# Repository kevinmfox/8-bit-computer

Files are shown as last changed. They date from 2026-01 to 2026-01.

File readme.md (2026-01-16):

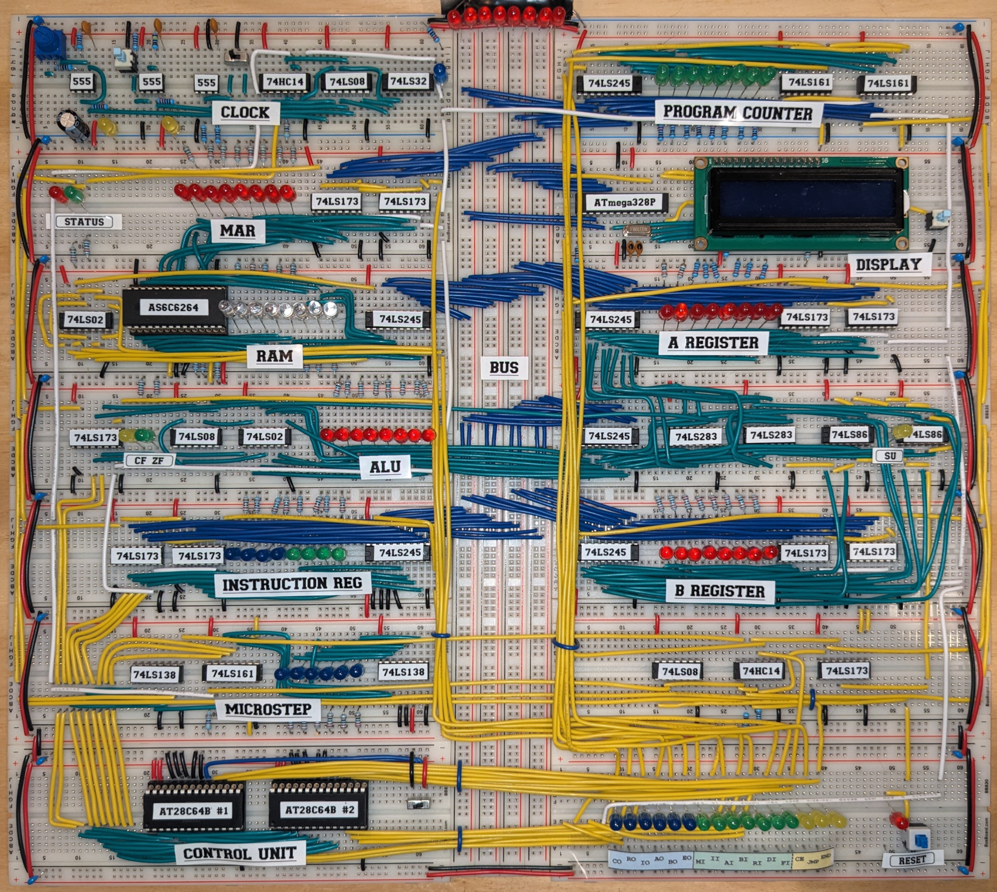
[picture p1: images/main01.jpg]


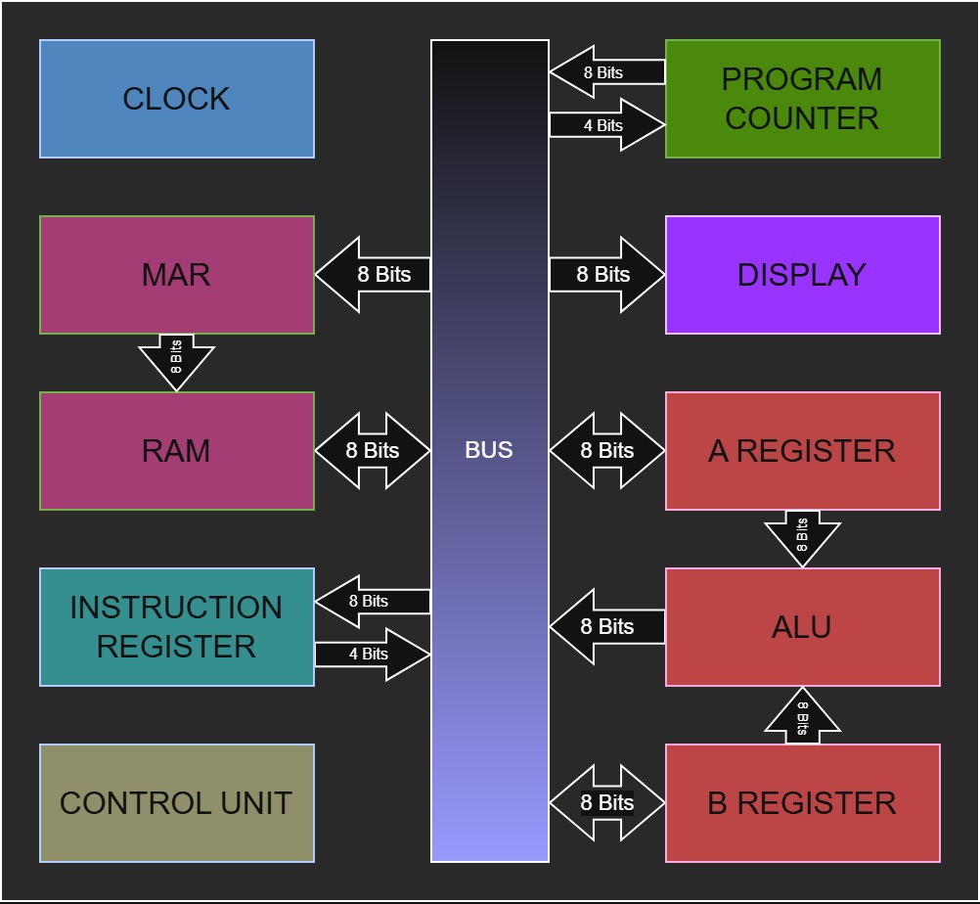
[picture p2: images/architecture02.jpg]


Credit to [diagrams.net](https://app.diagrams.net) for making the above image easy to do.

## Background

I came across Ben Eater's "8-Bit Computer" video series several years ago, and I thought it would be a really interesting project to take on. Over the course of the majority of my career (and most of my hobbies), my understanding of "computer systems" has been primarily focused on *things above the hardware layer*. 

In my early days I spent some time building systems, servers, etc., but when *the cloud* came along, much of that was *abstracted away from me*. I have some minor experience programming in assembly, and good amount of experience with higher-level programming languages. I'm also comfortable explaining computer architecture at an academic or conceptual level, but what was missing was a deeper, hands-on, understanding on how a computer works at the hardware layer. Actually building an "A Register". Having the Control Unit tell a register to put information on the bus, and having RAM store that information for later use. Understanding how the CPU clock works at the electrical level. Understanding how each integrated circuit plays its part in each CPU module...and so on. 

What better way to *bridge these gaps* than to build a super-simple 8-bit system.

I did post a video to YouTube covering much of this build as well, that can be found here: [https://youtu.be/7FzZS5qhdJ4](https://youtu.be/7FzZS5qhdJ4])

## Credit Where Credit's Due

Full credit to Ben Eater, the schematics on his website, and his tutorial videos. His videos were the original inspiration to attempt this project, and without those, I a) probably wouldn't have even thought to attempt this; and b) even if I did, building it would have taken me orders of magnitude longer.

YouTube series: https://www.youtube.com/watch?v=HyznrdDSSGM

Website: https://eater.net/8bit (https://eater.net/)

## Table of Contents

[The Build](build/readme.md)

Parts I used, my thoughts, learnings, observations, "gotchas", reference images, architecture stuff, etc. as I worked through the build.

[Schematics](schematics/readme.md)

Mostly so that, at some point in the future, I can reference how I did any of this.

[Instruction Set Architecture (ISA)](isa.md)

The 'spec' for my instruction set. Instructions, registers, flags, execution cycle, etc. Capabilities of the system and hardware expectations.

[Microarchitecture](microarchitecture.md)

My implementation of the ISA, covering the Modules, Control Signals, and other behaviour (e.g. system reset).

[EEPROM Programming - Python](/python/readme.md#microcode-generation)

The Python program (`generate_microcode.py`) I used to convert my control signals into *firmware* for my EEPROMs.

[EEPROM Programming - Arduino](/arduino/readme.md#eeprom-programmer)

Actually getting the EEPROM *firmware* onto the chips.

[The Compiler](/python/readme.md#compiling-programs)

A look at the Python compiler I used (`compile.py`) to convert my assembly files to machine code.

[Program Execution](/arduino/readme.md#ram-programmer)

How I took a compiled program and loaded it onto the system, and ran it.

## Other

The datasheets I used for the project can be found in the [datasheets](datasheets/) folder.

## What's Next?

I have a lot of thoughts on what I could do *next* as an extension to this project, but I promised myself I'd *step away* from it for a month or two.

Ideas for *Phase 2*:
- I think when the weather gets warmer I may construct a *shadow box* to store this project in (a fun link to my woodworking hobby)
- I'd like to learn how to convert this, or pieces of this, into PCBs
- If I do it (or similar) again, I may try to make the following architectural changes:
    - Either a 16-bit Instruction Register with an 8-bit Opcode and 8-bit Operand, or two seperate registers
    - An additional Register, just because you can never have too many ;)
    - Three EEPROM chips to support up to (e.g.) 24 control lines
    - Potentially some sort of user input (but that would require a bunch of other things)

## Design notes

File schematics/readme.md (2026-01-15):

# Schematics

## Overview

Schematics were built using KiCad: https://www.kicad.org/

It's free, open source, and for my purposes worked very well.

If I had my time back, I would have learned to use this *at the start*, or at least as I was working through the build. I tracked wire mappings and pinouts using a giant 700+ row spreadsheet. And, although that worked for me, it would have been way easier to troubleshoot had I just used the *right tool for the job* (e.g. KiCad).

The **Main** folder includes the main schematics for the actual build. 

The **Tooling** folding includes some additial schematics for things like the EEPROM and RAM programmers.

## Reading These With KiCad

Go get KiCad: https://www.kicad.org/

If you double-click on the `Main.kicad_pro` that'll open up the main build, and you can navigate through the schematics - it doesn't take much to learn how to crawl around these files. You can also open up individual schematics by double-clicking any `*.kicad_sch` file (e.g. `RAM Programmer.kicad_sch`).

## PDF Versions

I've included a few PDFs in the `schematics` folder. If you don't have or don't want to use KiCad, these can be used to review/map the build as well.

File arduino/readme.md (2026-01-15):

#  Arduino Programs

This area outlines the Arduino programs I used throughout the build. The assumption here is that you have an Arduino to use.

Below I've outlined the main programs, requirements, as well as some helpful notes for each.

Realistically, you probably shouldn't *tackle* the ROM programming until you're fairly certain what control signals you want your Control Unit to emit given specific inputs. This would necessarilly happen near the end of the build. Similarily, the RAM programming probably shouldn't be a priority until you've got your EEPROMs close to working.

## Display

This is the only aspect of the build where I think I *cheated* a little. In Ben Eater's original build (https://eater.net/8bit/output), he used four 7-segment displays along with a bunch of logic to produce output. I wanted to have something I could use to: a) troubleshoot easily; and, b) have multiple display modes (e.g. Hex, Binary, Decimal).

For example, I could tie `PIN 19` (`LATCH_MODE`) on the ATmega `LOW`, and the Display would continuously show what was on the bus (helpful for troubleshooting).

Requirements:
- Arduino for programming
- `ATmega328P` chip that will live on the build
- `1602A` 2-line display
- (optional) A push-button that could be used to switch modes

I would program the ATmega chip using the Arduino, and then put it on the board. It hasn't moved since.

Build info for the display can be found [here](/build/readme.md#display).

## EEPROM Programmer

Before programming these chips, you'll need to generate the actual ROM images. This can be done using the `generate_microcode.py` Python script (which assumes a bunch of other things). More details here: [Python](/python/readme.md#eeprom-programming)

I programmed each chip individually. Remove one from the board, program it, put it back, and repeat.

The `eeprom_programmer` folder contains the `microcode_images.h` file that was used for my project.

The sketch will prompt you to select which EEPROM you're programming.

Requirements:
- Arduino for programming
- Two EEPROM chips - I used `AT28C64B` chips
- The `microcode_images.h` file that holds the actual ROM images

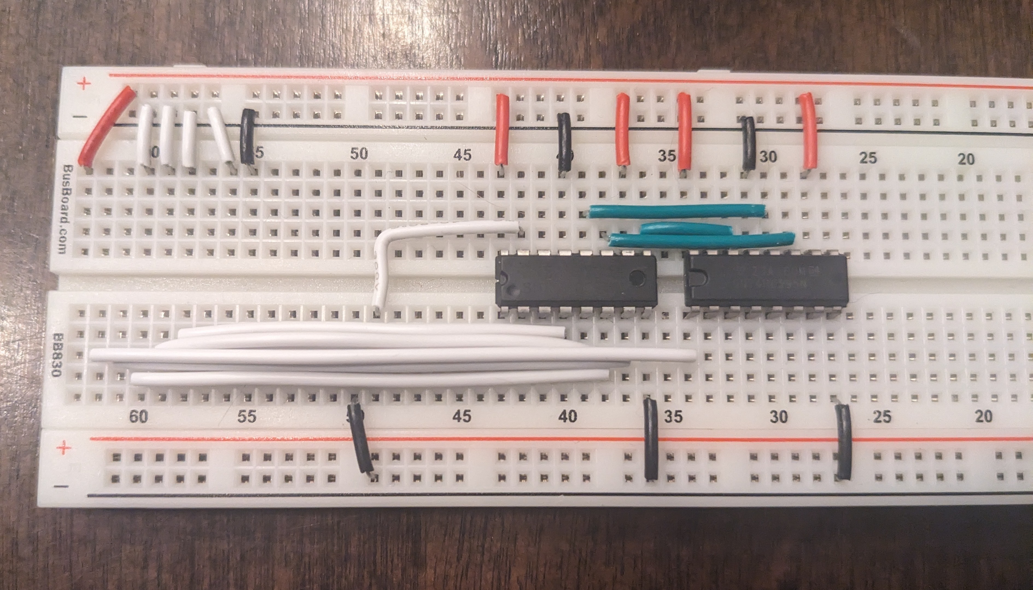
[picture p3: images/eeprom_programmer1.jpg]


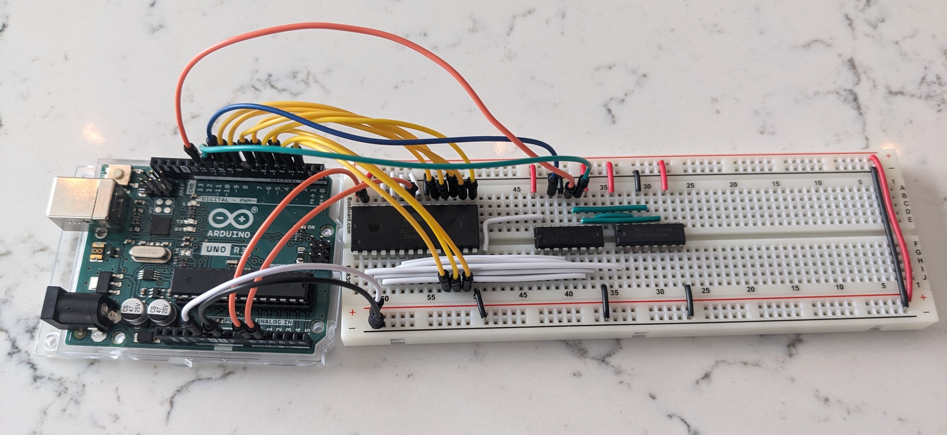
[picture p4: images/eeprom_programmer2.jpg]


## RAM Programmer

Similar to the EEPROM, you'll need to programs that can be run before you program the RAM chip. This also requires that the Control Unit EEPROMs be programmed (and preferably running properly).

Programs can be *compiled* using the `compile.py` Python script. More details here: [Python](/python/readme.md#compiling-programs)

The `ram_programmer` folder contains the `programs.h` file that was used for my project. It includes four test programs to ensure control signals are working as expected, and a couple *blinky light* programs for fun.

Requirements:
- Arduino for programming
- A RAM chip - I used `AS6C6264`
- Programs saved into `programs.h`
- Functional bus lines to read and write to the RAM chip
- Functional `CLK`, `/RI`, `/RO`, `/MI` lines to control program writing to the RAM chip

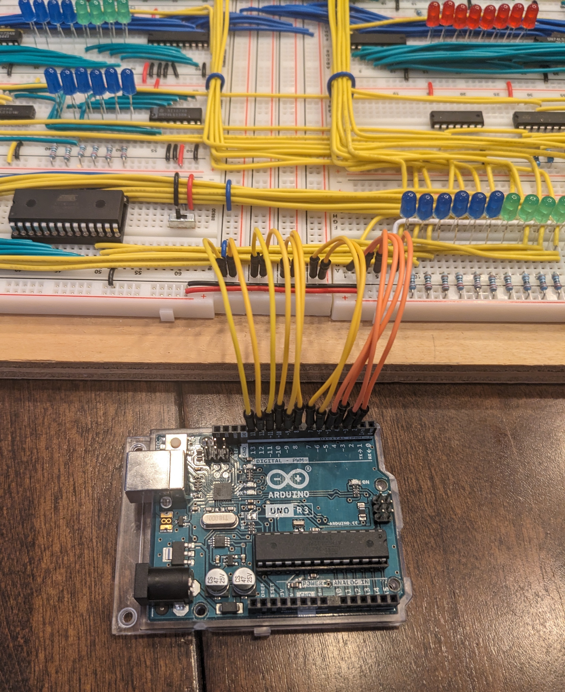
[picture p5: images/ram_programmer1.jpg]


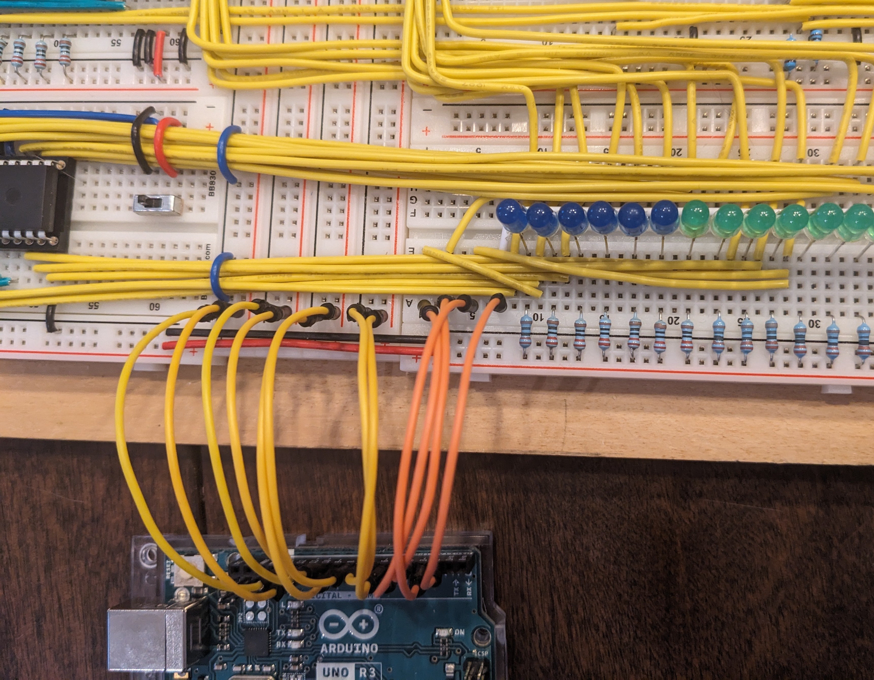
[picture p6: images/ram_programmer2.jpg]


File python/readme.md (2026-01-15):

## Microcode Generation

The `generate_microcode.py` Python script will generate the microcode from a given "signal truth table" (`assets\microcode.csv`) that can be put on EEPROMs.

The script can certainly be modified to take another or differntly formatted input, but the general idea is take your CPU input signals, and convert those into expected output signals.

In my case, the input signals were:
- `Opcode` - Four bit binary representation (e.g. `0101`)
- `T-Step` - Represented as `T0` through `T5` (depdnding on the instruction)
- `CF` - The state of the Carry Flag (`0` or `1`)
- `ZF` - The state of the Zero Flag (`0` or `1`)

The `T-Step`, `CF`, and `ZF` inputs can also take wildcards (`*`) which will be *expanded* to cover all posibilities.

The outputs will be whatever control signals you want active given the inputs.

For all instructions, the final step is an `END` signal, which tells the Microstep Counter to go back to `T0`.

In my case, I had my `assets\microcode.csv` file represented as active-high (i.e. 1 = ON), but the actual script will generate active-low signals, as that's what my board expected.

Note the `Address`, and `Mnemonic` fields in the `microcode.csv` file aren't actually used in the Python script, but are there simply for reference.

I programmed an Arduino to program my EEPROM chips. Steps on getting the generated microcode onto an EEPROM chip can be found [here](/arduino/readme.md#eeprom-programmer).

Sample commands:
- `python .\generate_microcode.py`

## Compiling Programs

The actual `compile.py` Python script is not much more than a generic text parser and mapping algorithm. Read a line; parse/extract/scrape certain portions; make decisions based on the inputs; output some other text. I'm not trying to downplay the importance of this, or suggest all compilers are this simple (they're not), but provided your instruction set is *simple*, and you are rigid in what you allow for your assemlby language, it's fairly straightforward. 

The compiled instructions obviously have to align with the microcode you've put on your ROMs.

So, if you give an instruction such as `ADI 0x8`, the expected compiled line would be:
- Opcode = `ADI` = `0101` or `0x5`
- Operand = `0x8` = `1000` or `0x8`
- Instruction = `0101 1000` or `0x58`

Given the limitation of a 4-bit Operand, you should be cautious when compiling programs that use `STA` instruction. This instruction will *store* the value of the A Register into the memory address of the Operand. But, if your programs runs into that same space, you may have inadvertently overwritten some of your program. My compiler doesn't check for this, and I didn't think I needed it to until I did this about a dozen times to myself ;).

The compiler supports some basic sanity checks:
- Address out of range for my architecture (i.e. referencing something above 0xF)
- Invalid instructions
- Missing Operands or Operands on instructions that expect none (e.g. `NOP`)

The compiler supports:
- Jump labels
- Using hex (e.g. `0xF`), binary (e.g. `0b1111`) or decimal (e.g. `15`) for Operands
- Comments

Given a text file input (by convention I've labelled these ASM files), it will print the compiled code to screen. This can be copied/pasted into the `programs.h` file for the [Arduino Programmer](/arduino/readme.md#ram-programmer).

I used an Arduino to program my RAM chip while it was on the board. Steps on getting these programs onto the board can be found [here](/arduino/readme.md#ram-programmer).

Sample commands:
- `python .\compile.py --program-name TEST assets\program-test01.asm`
- `python .\compile.py --program-name DEMO01 --print-summary .\assets\program-demo-01.asm`

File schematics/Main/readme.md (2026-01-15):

# Main Schematics

Once you load the `main.kicad_pro` file in KiCad, it's easy enough to see the main layout and click through the various module schematics.

While I made efforts to align my schematics to what I actually built, there is some variation. This was usually caused by either space constraints or moving something to a location where it would *make more sense*. A few examples: 

- The build has the Status Lights (Red = Halt; Green = Running) on the Memory Address Register board.
- The physical ALU spans across two horizontal breadboard, where my schematic may imply otherwise.
- The build has the `HLT` and `SU` decoding on the Microstep Counter board (there was just more room) vs. the Instruction Register.
- The build has a completely separate board for some *auxiliary* chips used by the Control Unit due to space constraints, and it also holds the `74LS173` chip for the `SU` Flag. I also used the `74HC14` inverter on this board to help with other inversions.
- The Control Unit spans across two breadboards (chips & LEDs).

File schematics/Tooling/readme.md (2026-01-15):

# Tooling Schematics

Both the EEPROM and RAM programmer used an Arduino Uno for programming.

More detailed requirements can be found in the respective `arduino` programs. These sketches simply outline how I programmed these chips.

## EEPROM Programmer

Used the sketch found in [arduino/eeprom_programmer](../../arduino/eeprom_programmer).

Each EEPROM chip was programmed individually (i.e. remove chip from board; program it; put it back; repeat).

## RAM Programmer

Used the sketch found in [arduino/ram_programmer](../../arduino/ram_programmer).

The Arduino was hooked up directly to the project via the bus and several control lines (`CLK`, `/MI`, `/RI`, `/RO`).

It's important that the Arduino is the only thing driving the bus, that the Control Unit is 'disconnected', and the Clock isn't running. In my build, I used a toggle switch to *disconnect* the Control Unit and stop the Clock.

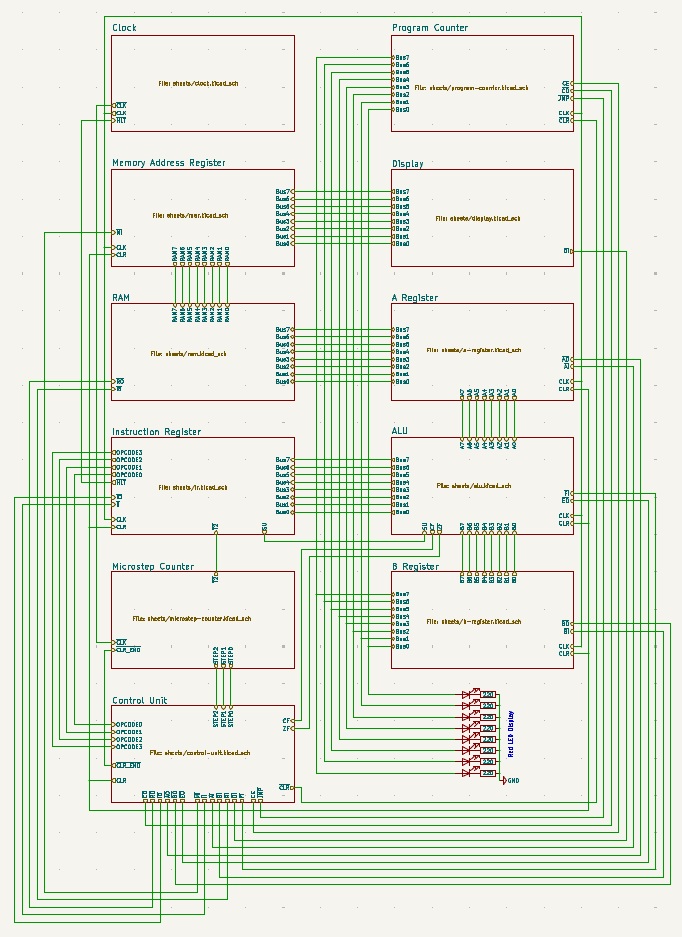
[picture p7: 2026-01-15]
images/architecture01.jpg

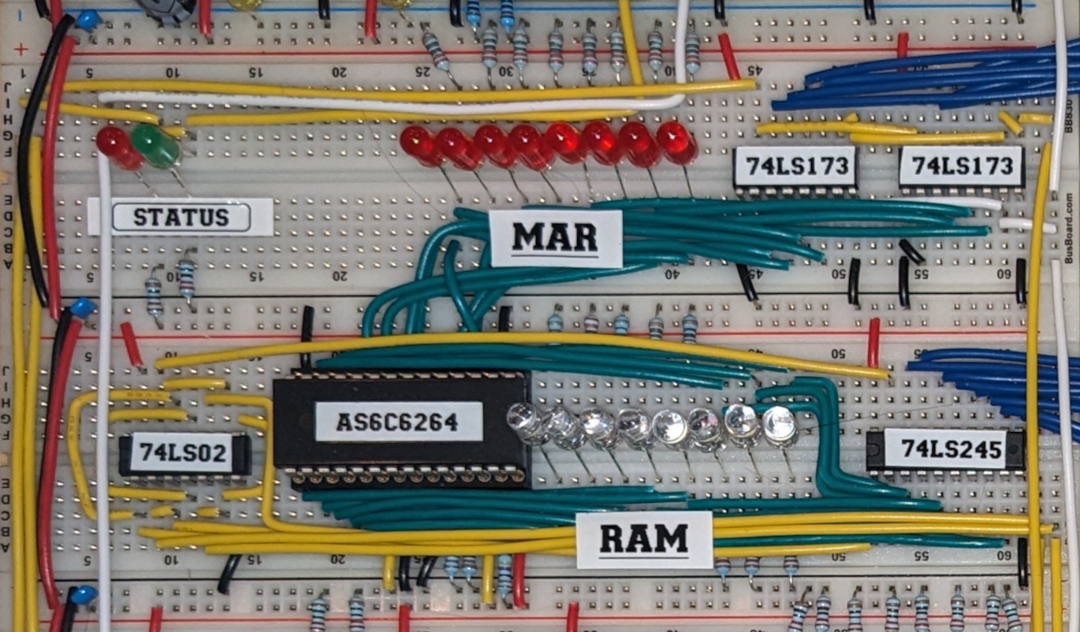
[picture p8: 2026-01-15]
images/mar_ram01.jpg

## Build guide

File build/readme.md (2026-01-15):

# The Build

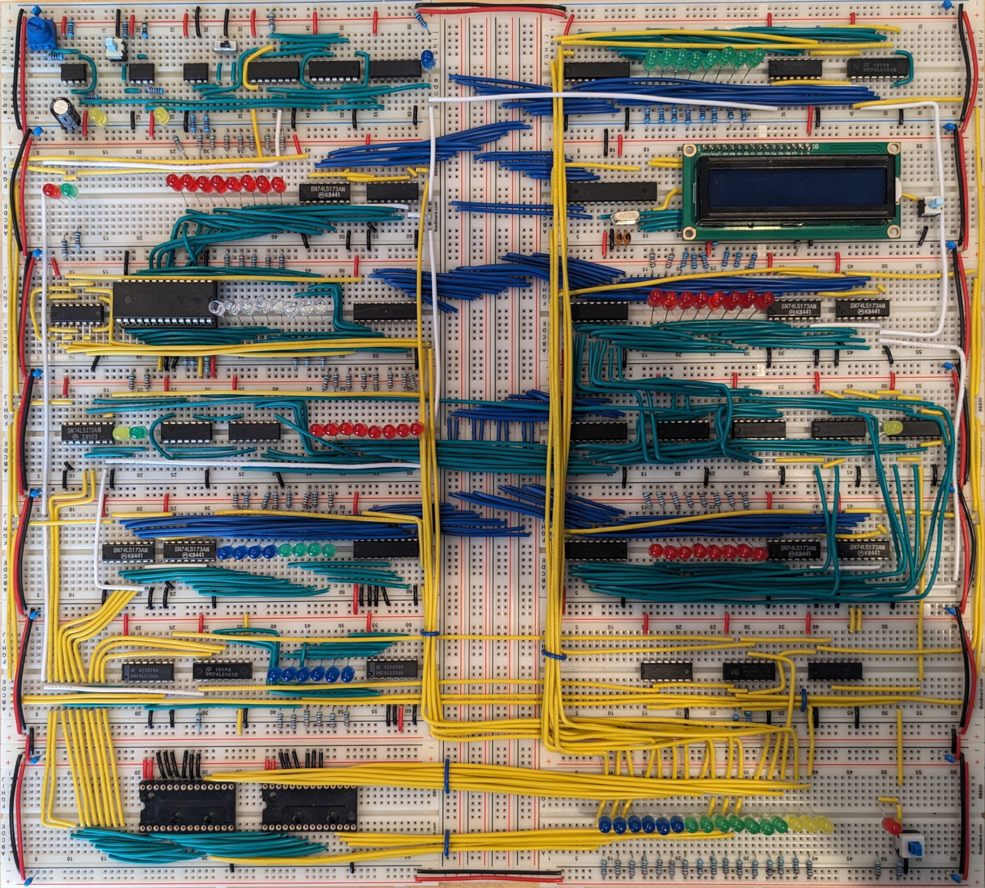
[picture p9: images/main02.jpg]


## Inventory

Here's a rundown of all the parts I used. It should be *pretty close* to accurate ;)

Notes:
- I only used a single 100 nF decoupling capacitor per breadboard module. I know *best practice* is to have a decoupling capacitor on every IC. I didn't have any issues, but take note.
- I used [BB830 breadboards](https://www.amazon.ca/BusBoard-Prototype-Systems-BB830-Solderless/dp/B0040Z4QN8) almost exclusively (I had a couple laying around before I started). Seriously, if you're going to do this, don't go cheap on breadboards. I tried saving a couple dollars at a local electronics shop, and the boards were inconsistent at best.
- For wiring I bought two of [these kits](https://www.amazon.ca/dp/B0CM2Y7V1Z). For those interested, I used: 10.4 feet or red wire, 13.7 feet of white wire, 14.3 feet of black wire, 30.0 feet of blue wire, 57.3 feet of yellow wire, and 59.0 feet of green wire. 184.7 feet of wire (not account for mistakes or rework!)

| Type | Value | Quantity | Notes |
|---|---|---|---|
| Capacitor | 1 µF | 1 | 555 astable capacitor |
| Capacitor | 10 nF | 3 | 555 signal conditioning |
| Capacitor | 100 nF | 14 | Decoupling capacitors - one per breadboard module |
| Capacitor | 22 pF | 2 | For the 16 MHz Crystal on the ATmega driving the Display |
| LED | 5 mm Yellow | 6 | Generally used for Flags and a few Control indicators |
| LED | 5 mm Green | 21 | Program Counter, Operand, and input Control indicators |
| LED | 5 mm Red | 42 | MAR, A & B Registers, ALU result, and Bus indicators |
| LED | 5 mm White | 8 | Only used on the RAM module |
| LED | 5 mm Blue | 17 | Clock pulse, Opcode, Microstep Counter, and output Control indicators |
| Resistor | 220 Ω | 95 | LED current-limiting resistors, including the 1602A display |
| Resistor | 1 kΩ | 3 | 555 astable timing (R1), 555 monostable debounce, and 1602A display contrast |
| Resistor | 330 Ω | 1 | 555 astable timing (R2) |
| Resistor | 1 MΩ | 1 | 555 monostable timing |
| Resistor | 4.7 kΩ | 6 | Various pull-ups and pull-downs |
| Potentiometer | 0-200 kΩ | 1 | Clock speed adjustment (555 astable) |
| Switch | Slide switch | 2 | Clock mode, and Control Unit enable/disable |
| Push Button | Momentary | 3 | Clock step, Display mode, and Reset buttons |
| Display | 1602A LCD | 1 | Arduino-driven output display |
| Crystal | 16 MHz | 1 | ATmega328P clock source |
| IC | LM555 | 3 | Clock module (astable, monostable, selector) |
| IC | ATmega328P | 1 | Display controller |
| IC | 74LS08 | 3 | AND gates - Clock, ALU, and Control Unit logic |
| IC | 74LS245 | 6 | 8-bit bus transceivers |
| IC | 74LS161 | 3 | Binary Counter - Program Counter, Microstep Counter |
| IC | 74LS173 | 10 | Register data - MAR, A, B, IR, Flags |
| IC | 74HC14 | 2 | Schmitt trigger inverters |
| IC | 74LS32 | 1 | OR gates -  Clock |
| IC | 74LS02 | 2 | NOR gates - RAM signal logic, ALU |
| IC | 74LS138 | 2 | 3-to-8 Decoder - IR, Microstep Counter |
| IC | 74LS283 | 2 | Binary adders - ALU |
| IC | 74LS86 | 2 | XOR gates - ALU subtraction |
| Memory | AS6C6264 SRAM | 1 | Main RAM |
| Memory | AT28C64B EEPROM | 2 | Microcode ROMs |
| Breadboard | BB830 | 14 | To connect everything |

## Modules

[Clock Module](#clock-module)

[Program Counter](#program-counter)

[Display](#display)

[Memory Address Register (MAR)](#memory-address-register-mar)

[Random Access Memory (RAM)](#random-access-memory-ram)

[A & B Registers](#a--b-registers)

[Arithmetic Logic Unit (ALU) & Flags](#arithmetic-logic-unit-alu--flags)

[Instruction Register](#instruction-register)

[Microstep Counter](#microstep-counter)

[Auxiliary Board](#auxiliary-board)

[Control Unit](#control-unit)

## Clock Module

The Clock module was an interesting aspect of this build because it serves a distinctly unique purpose compared to all other modules. It's sole purpose is to *emit* a clock pulse - that's it. It could have been a single 555 timer chip, a capacitor, and a couple resistors. It's the ability to select between modes (astable vs. mono), adjust the speed via the potentiometer, and halt the clock that accounts for the bulk of the complexity.

With the exceptions that I kept the LEDs to indicate the astable tick and the mono step, and I used 74HC14 Schmitt invertger to *clean up* and invert my `HLT` and `CLK` signals, what I built was right out of [Ben Eater's tutorials](https://eater.net/8bit/clock).

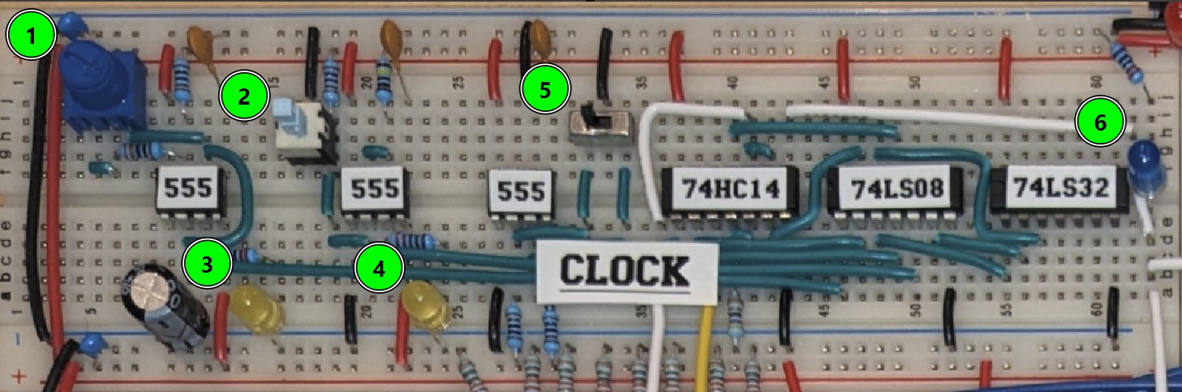
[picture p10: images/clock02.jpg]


- #1 - Potentiometer to adjust the clock speed
- #2 - Pushbutton to send a single pulse (assuming in mono mode)
- #3 - Astable LED
- #4 - Monostable LED
- #5 - Slider to control astable or mono mode
- #6 - Final clock output

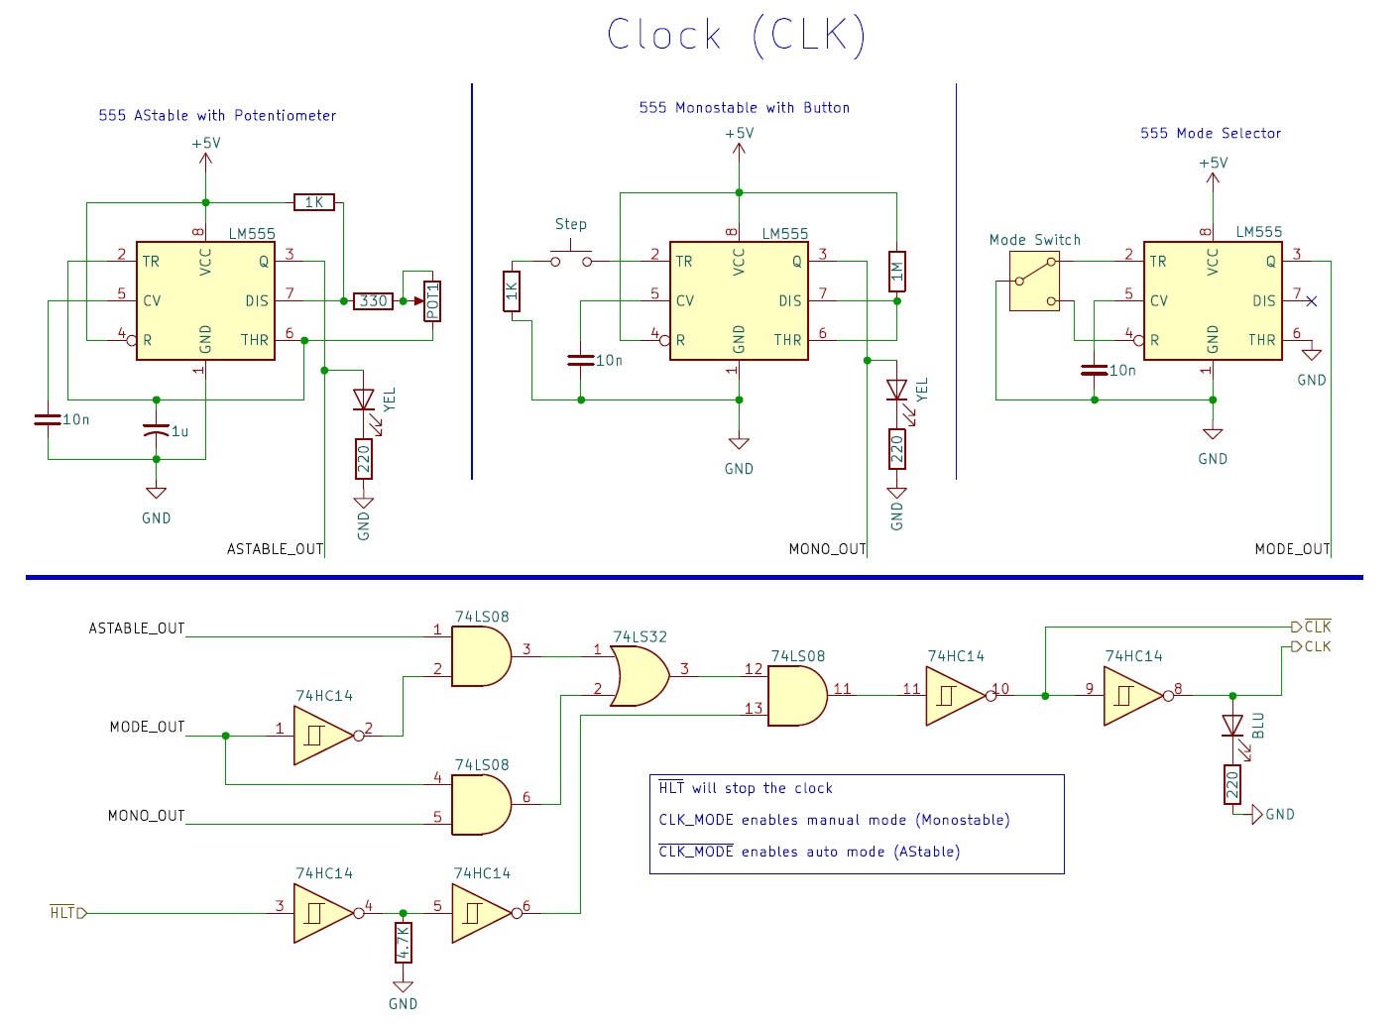
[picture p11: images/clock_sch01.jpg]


## Program Counter

Not much difference here vs. Ben's build with the exception that I made my Program Counter a full 8 bits vs. Ben's 4 bits. Practically speaking, this made little difference, but it did give me the option to do a full 8-bit IR later on (which I didn't), and also allowed me to run the program space beyond 16 bits (which I did on occasion).

I messed this portion of the build up twice! This was the second module I worked on, so I hadn't fully conceptualized the build in my head yet (excuses). My bus runs MSB (left) to LSB (right). The 74LS245 chip, when placed PIN 1 bottom-left, runs opposite - LSB > MSB  (if you're using PIN numbers and labels as your guide). Additionally, the 74LS161s (assuming PIN 1 bottom-left) also runs the same as the 74LS245 - LSB > MSB. I was testing my `JMP` command, and realized the data coming back in from the bus was backwards. So, I ripped it all up, rewired it, and then the data coming from the bus was correct, but the data coming from the Program Counter was entering the bus backwards *sigh*. Got it right on the third attempt.

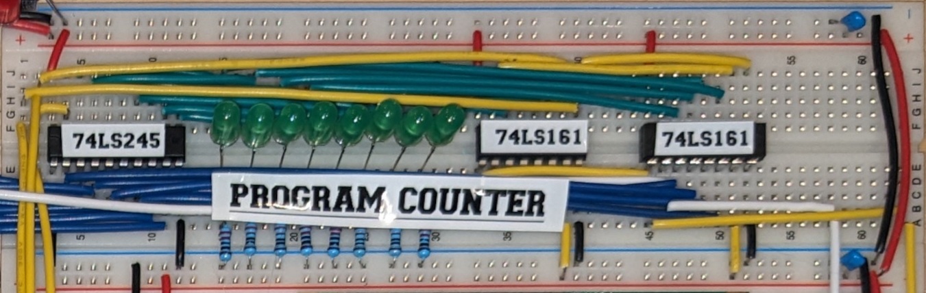
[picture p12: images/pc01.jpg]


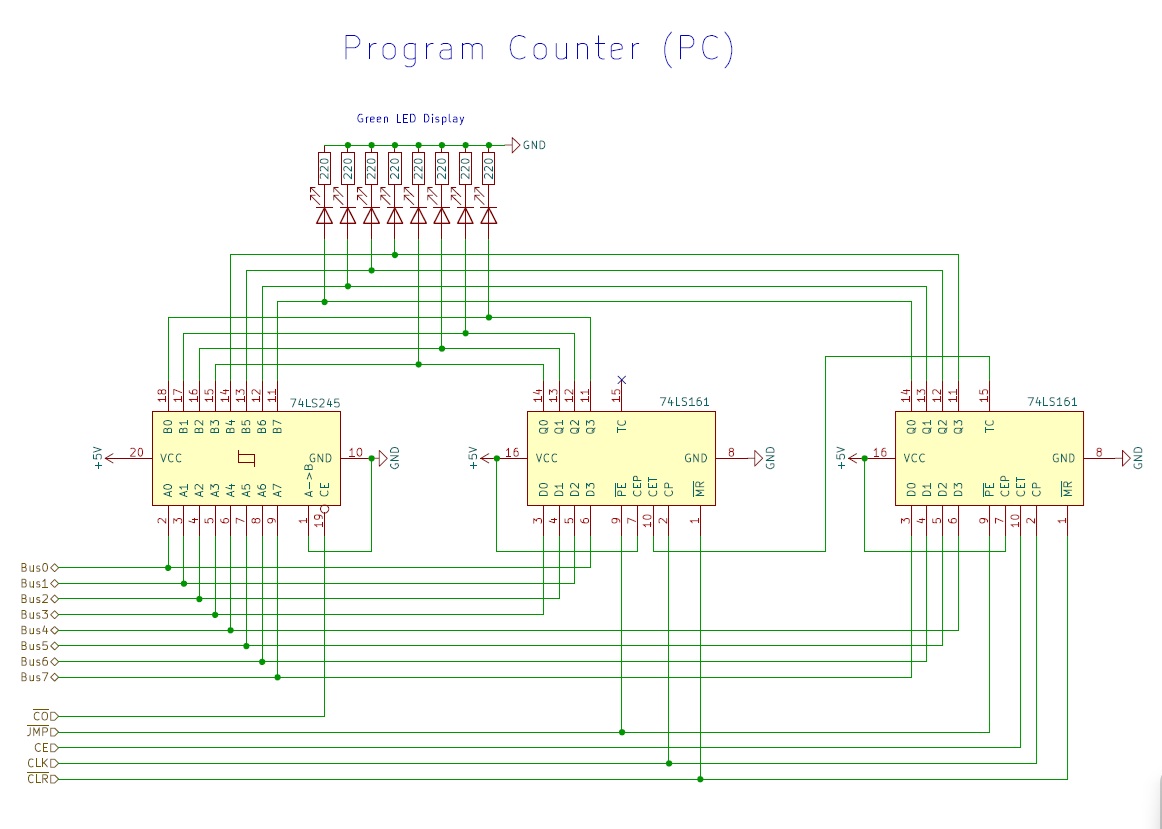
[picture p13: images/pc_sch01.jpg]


## Display

A somewhat controversial *pivot* here ;). This deviated dramatically from Ben's initial build. I *cheated* and used an ATmega328P to run my display output. This (clearly) wasn't about saving space, wires, or chips, but more that I wanted to use the 1602A LED display I had sitting around, and also wanted to be able to view hex, decimal, and binary in a single spot - this solved that. 

I incorporated a pushbutton that would allow me to switch between modes. And I also programmed PIN 19 on the ATmega to allow me to constantly *pull* the bus if it was enabled (wired to ground or pulled low).

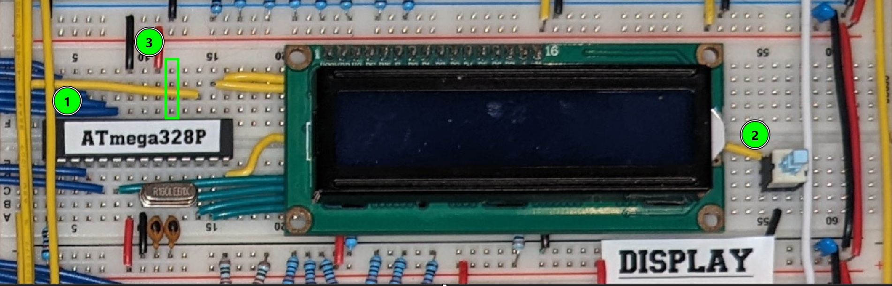
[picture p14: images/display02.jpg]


- #1 - The notorious ATmega chip
- #2 - Pushbutton to change display modes
- #3 - PIN 19 on the ATmega to allow pulling from the bus directly (shown in the image below)

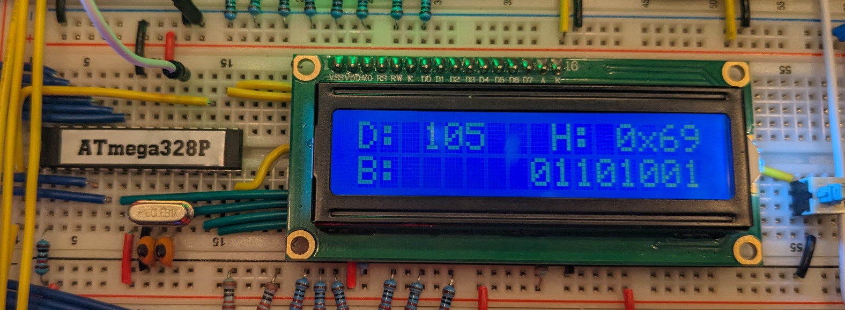
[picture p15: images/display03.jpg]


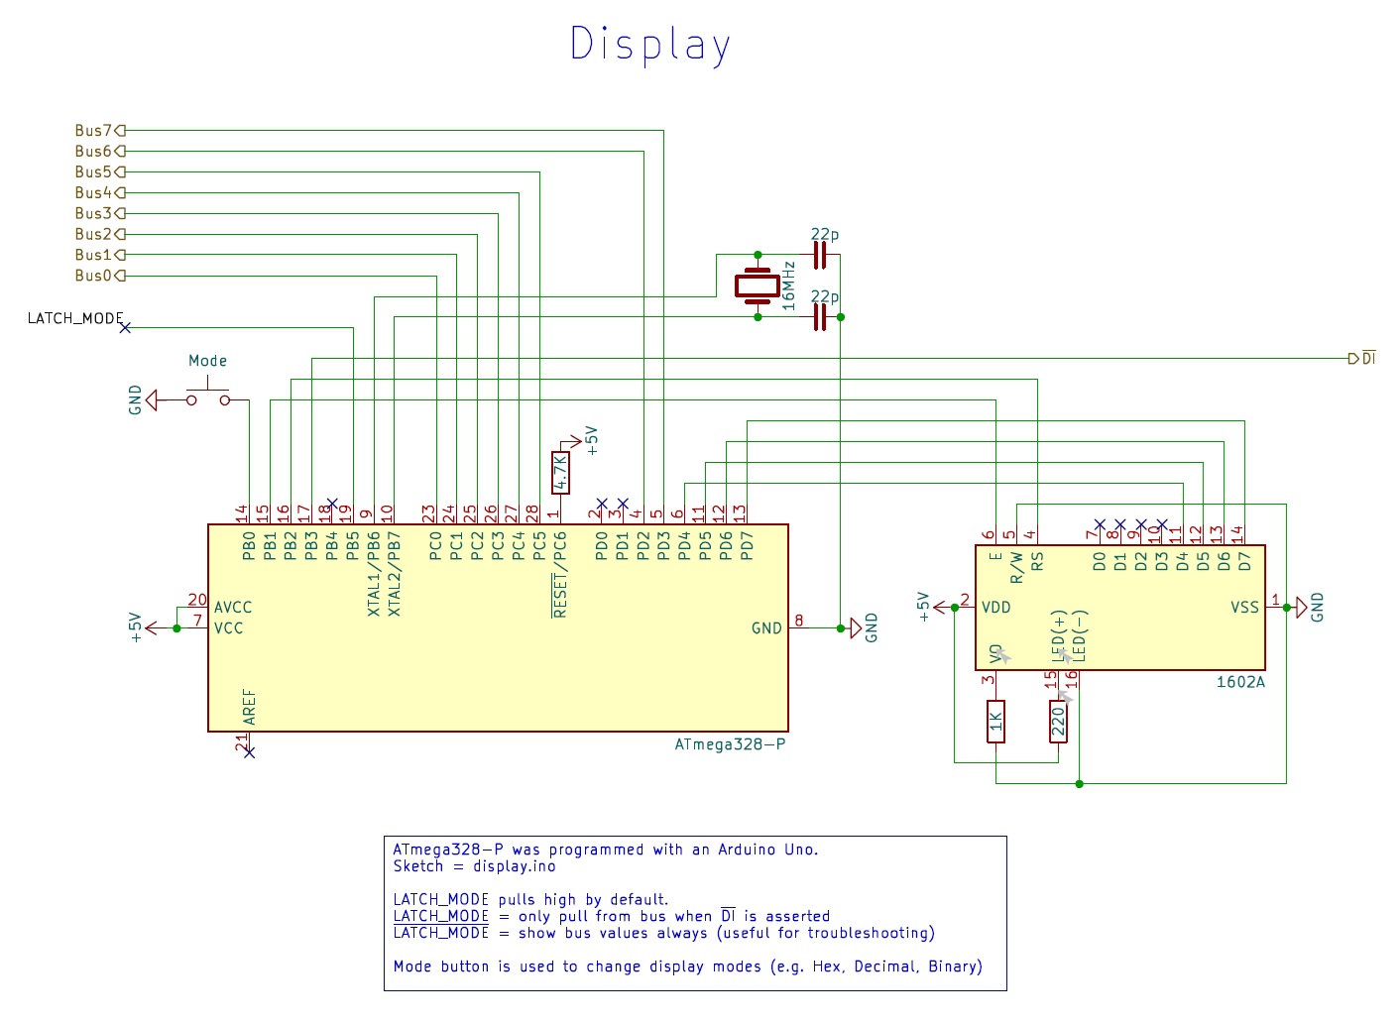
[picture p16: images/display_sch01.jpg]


## Memory Address Register (MAR)

Because I had a full 8-bit Program Counter, I needed an 8-bit Memory Address Register (what the Program Counter puts onto the bus the MAR picks up). I also opted not to have DIP switches on my build for either the MAR or the RAM. This made initial testing a little more difficult, but it did give me more space to work with.

I also had my status LEDs on this board. This made sense as a) there was actually some room here; and, b) it was close to the clock which received the `HLT` signal.

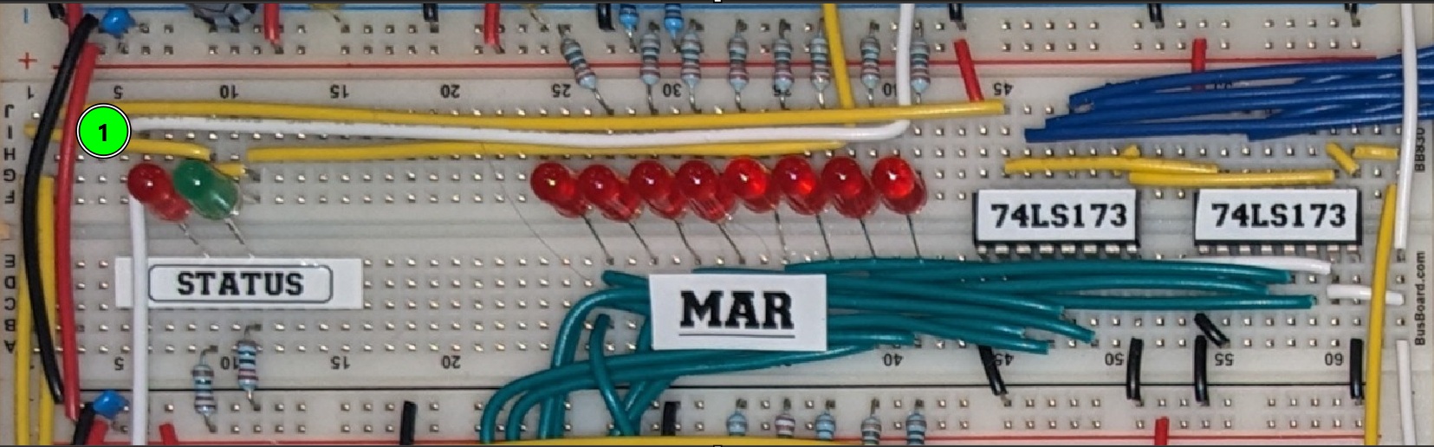
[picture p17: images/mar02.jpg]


- #1 - Status LEDs. Green = running; Red = `/HLT` received (i.e. stop the clock output)

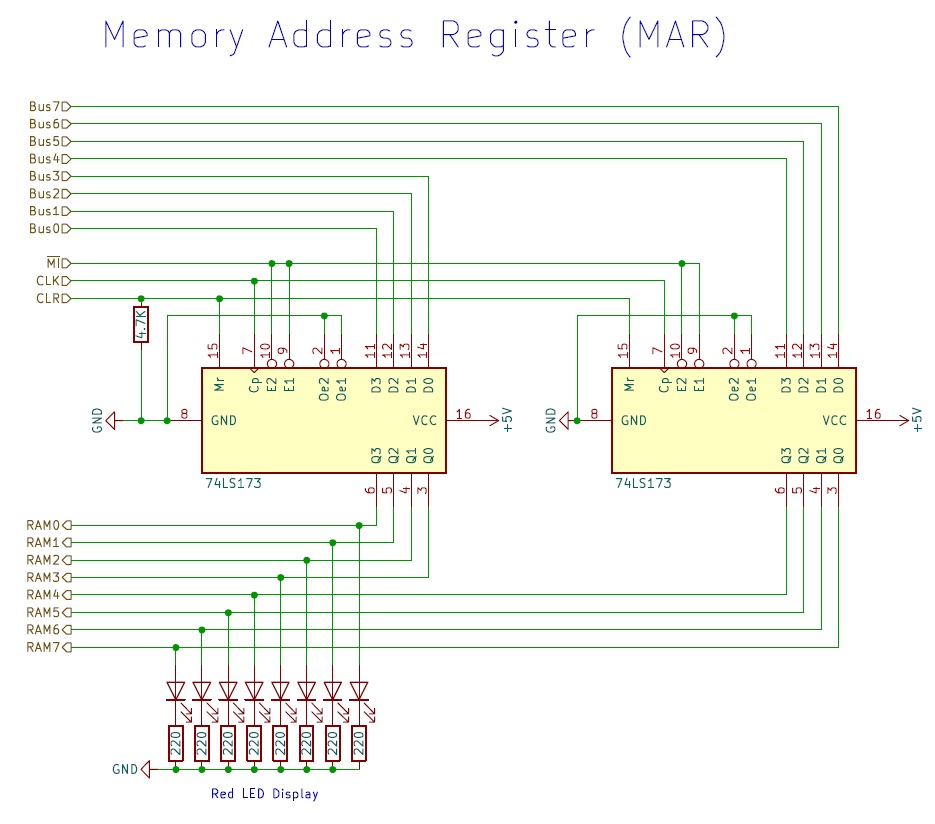
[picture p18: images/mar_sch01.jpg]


## Random Access Memory (RAM)

Ben's build *called for* some 74189 chips for the RAM. I couldn't find those readily available, so I went with a single AS6C264 chip. This was also one of the few chips I *rotated* (PIN 1 top-right) so that it was easier to run my wiring (MAR above).

I used white LEDs for the RAM, and although this seemed *neat* at the time, I'll probably swap them for anything but. I've only got 220 resistors on them, and they can be blinding if I'm standing over them.

Although not stricly required, I gated my RAM with a 74LS245 chip. I needed this as I wanted the LEDs to always show what the RAM was seeing. This required the `/OE` PIN on the RAM to be enabled by default. Without the 74LS245, it would always be driving the bus.

Finally, you'll notice the *rats nest* of wiring around the 74LS02 NOR chip. I was quite happy that I was able to send two signals (`/RI`, `/RO`) up to this chip, and it would do the logic to control the AS6C264 RAM signals (`/OE`, `/WE`) and the 74LS245 signals (`DIR`, `/CE`).

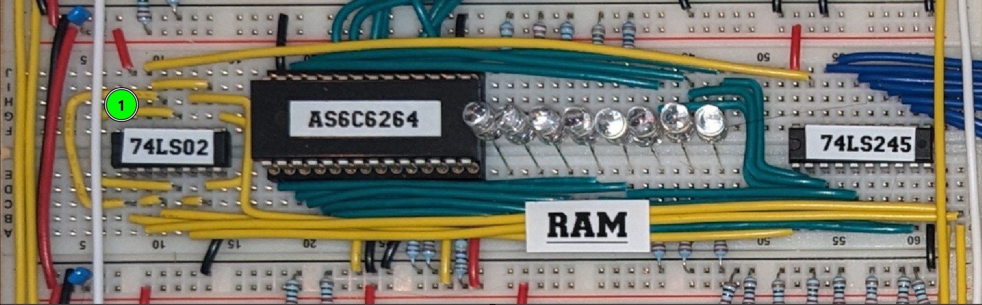
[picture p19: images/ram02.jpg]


- #1 - 74LS02 NOR gate used to perform *magic*. Logic can be seen in the image below.

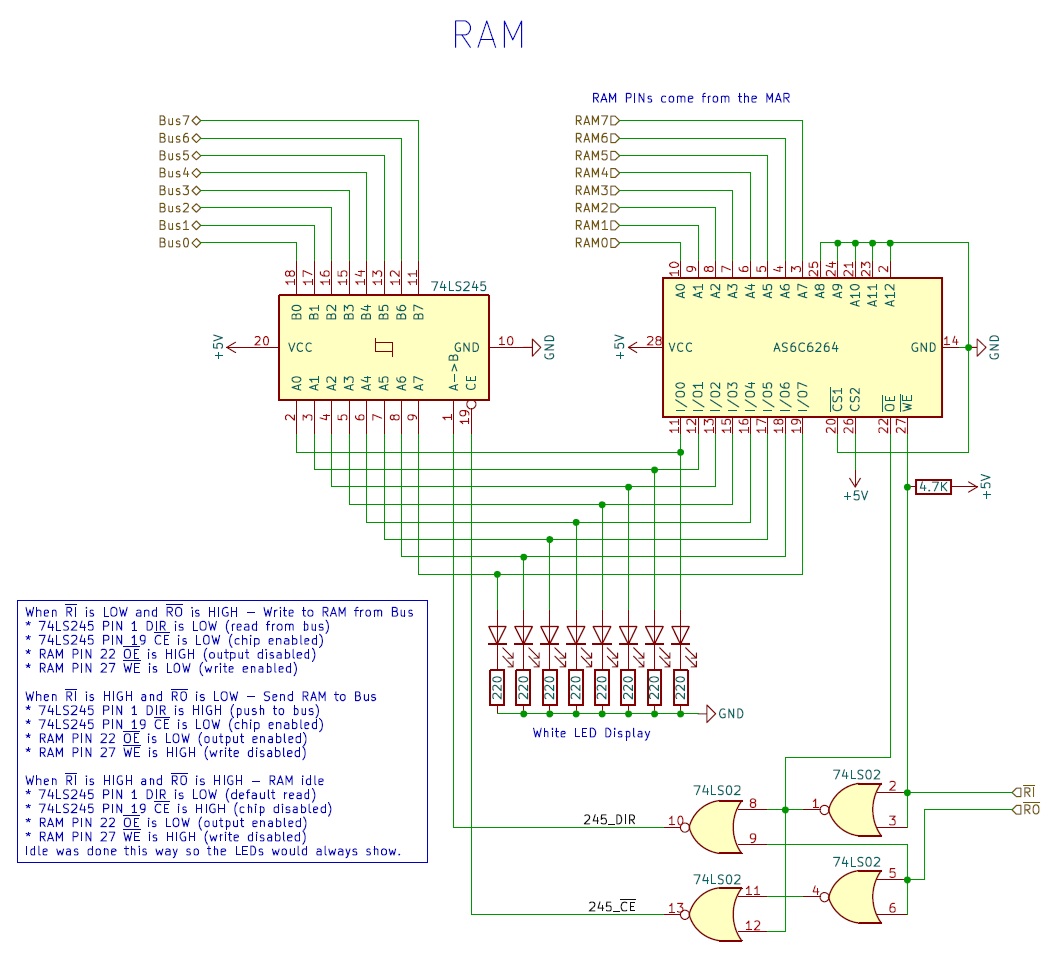
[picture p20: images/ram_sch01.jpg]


## A & B Registers

I think these two registers were piece-for-piece identical to Ben Eater's build. Same chips, same LEDs, same signals. 

If you're going to take on this project (or similar), I recommend *batch building* your registeres.

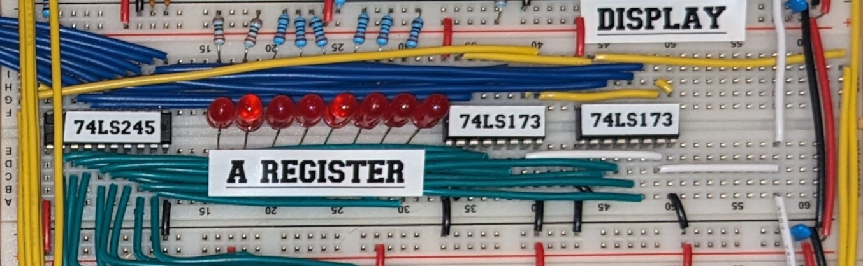
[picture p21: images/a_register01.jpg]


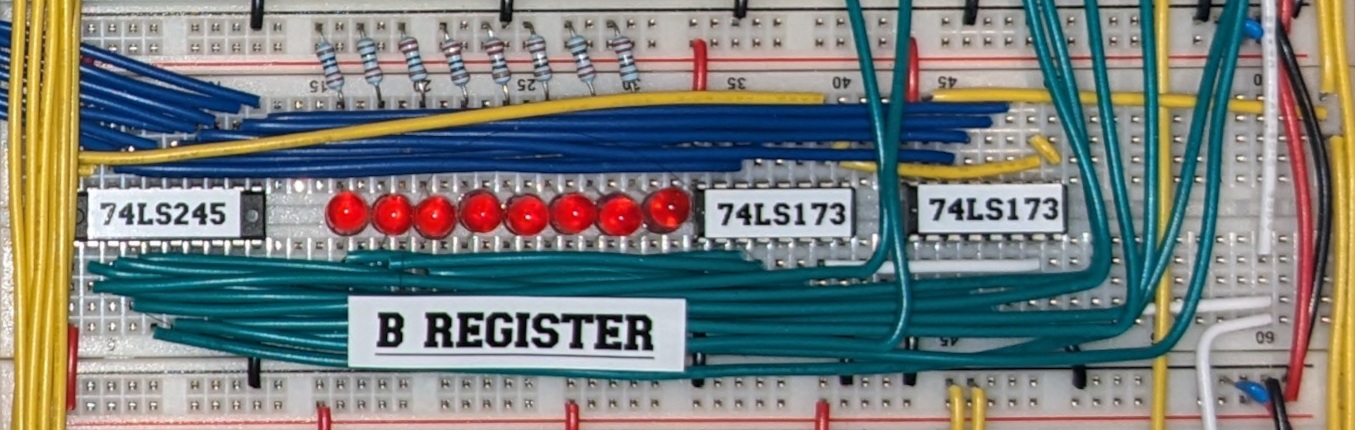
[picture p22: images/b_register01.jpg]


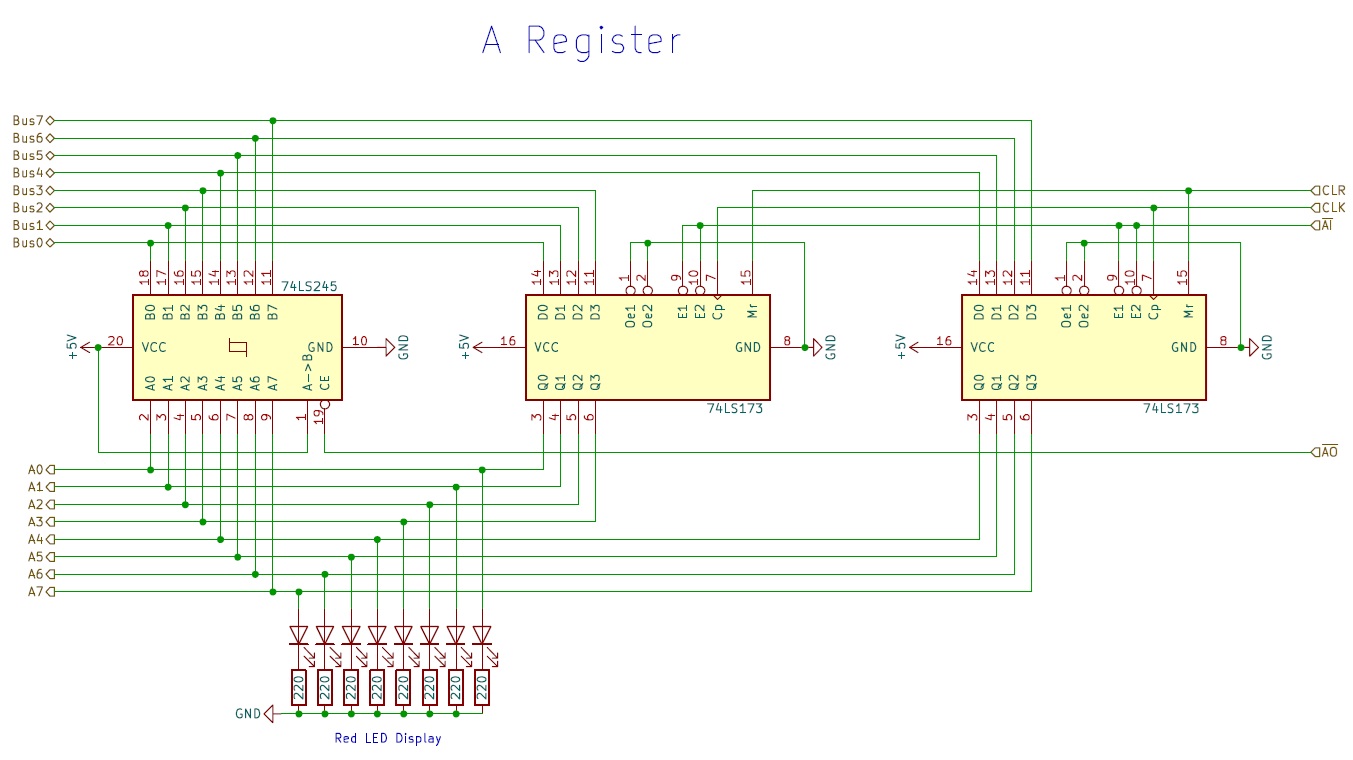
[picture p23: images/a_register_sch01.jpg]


## Arithmetic Logic Unit (ALU) & Flags

I'm happy to say that my ALU almost worked the first time I hooked it up...almost. After spending a few hours double checking to ensure the ALU was getting the *right information* from my registers (it wasn't), I started probing PINs on the 74LS283s and 74LS86s until I could find what was wrong. Like most *breadboard stories*, it turned out that I had a single wire in *off by one* column. As you can imagine, in the world of binary math, that's enough to cause chaos.

This is probably my *messiest* board, and if I had the patience, I'd go back and rewire some of it. I also considered trying to fit the entire ALU on the right side of the build, but after some scenario planning, this was the location that made the most sense for me.

The Subtract flag (`SU`) is indicated on the right-side of the build. The Carry and Zero flags (`CF`, `ZF`) are indicated on the left side of the build.

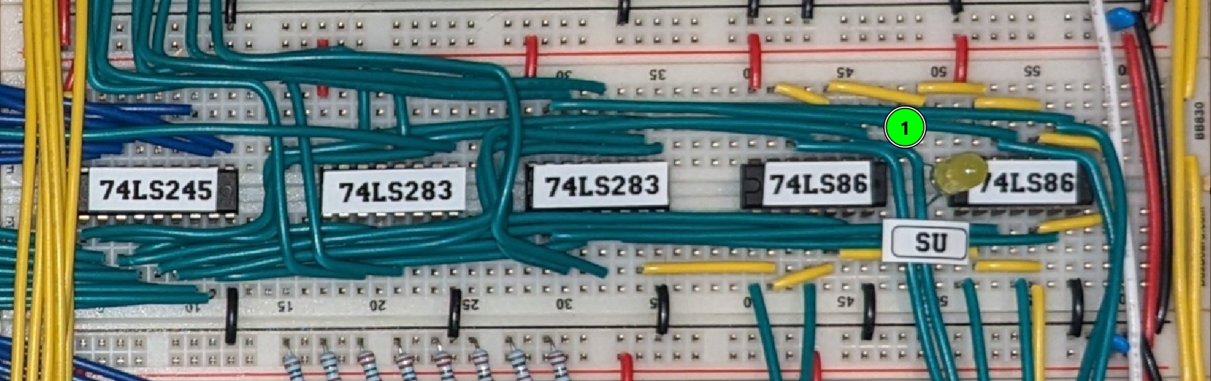
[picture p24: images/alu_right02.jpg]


- #1 - The Subtract flag indicator

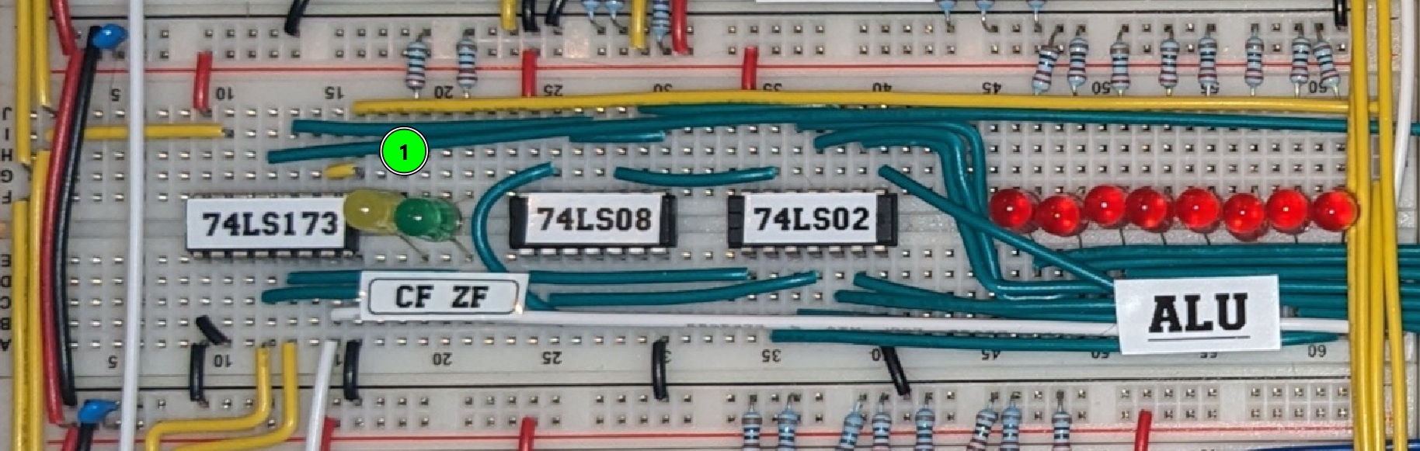
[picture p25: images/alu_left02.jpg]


- #1 - The Carry & Zero flag indicators

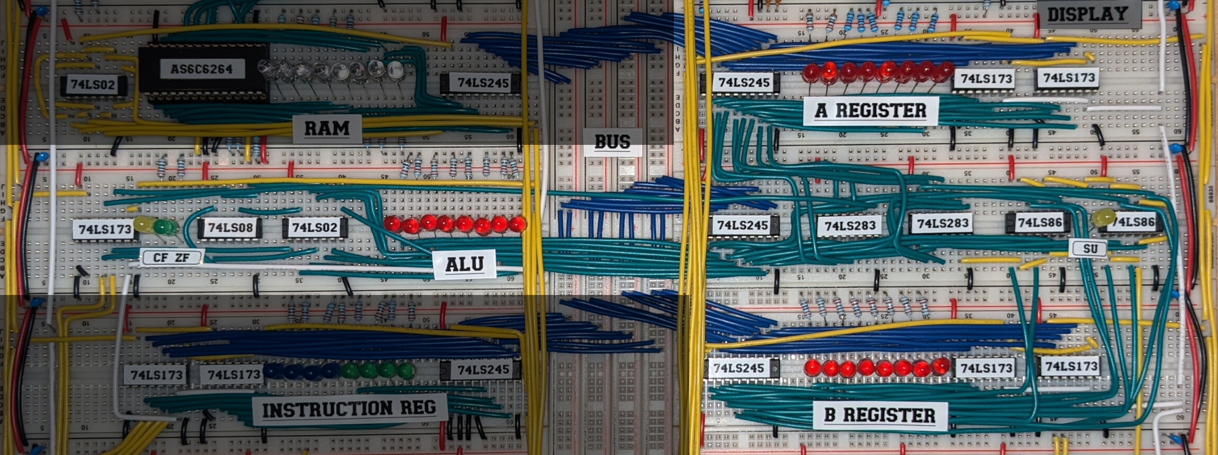
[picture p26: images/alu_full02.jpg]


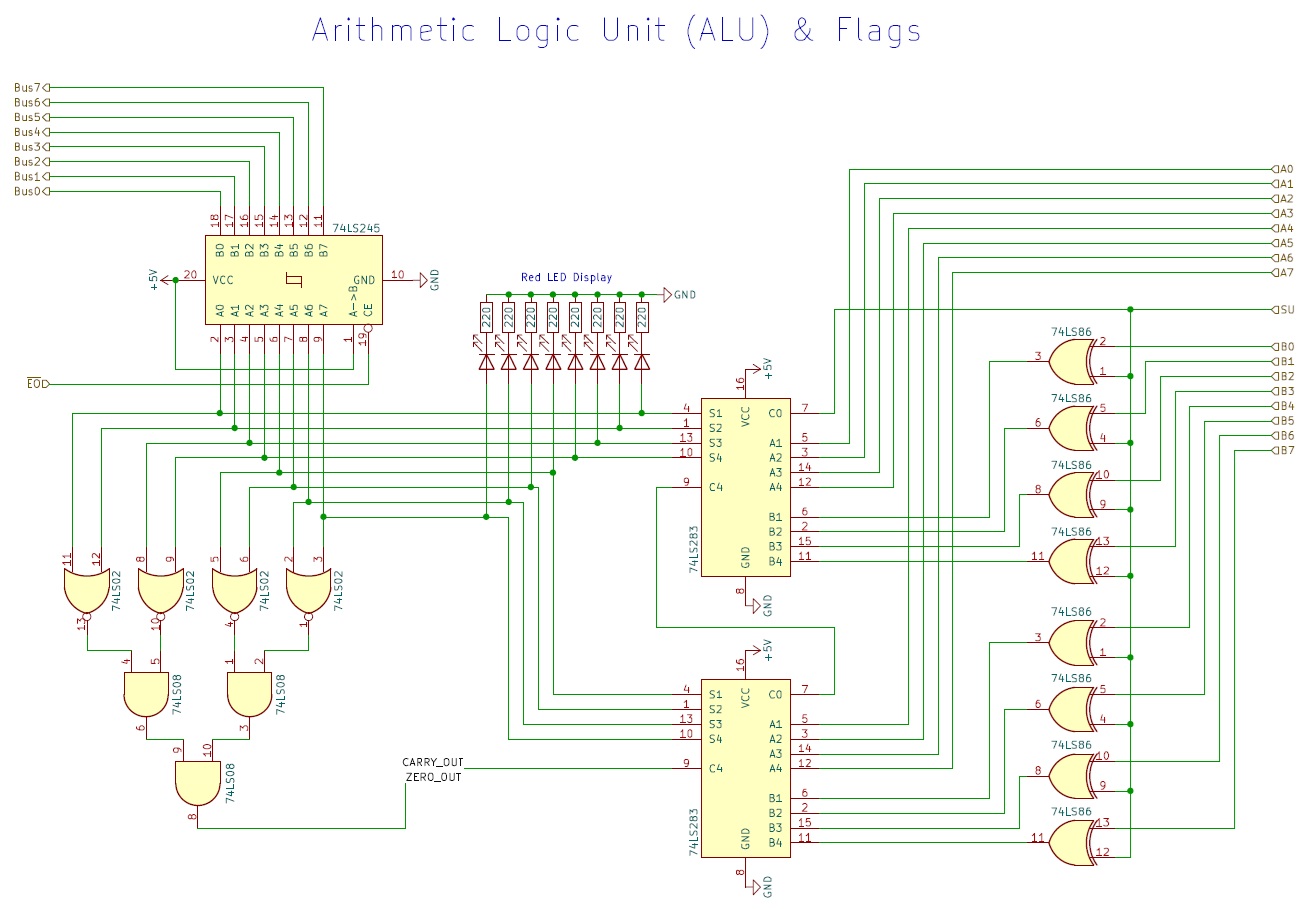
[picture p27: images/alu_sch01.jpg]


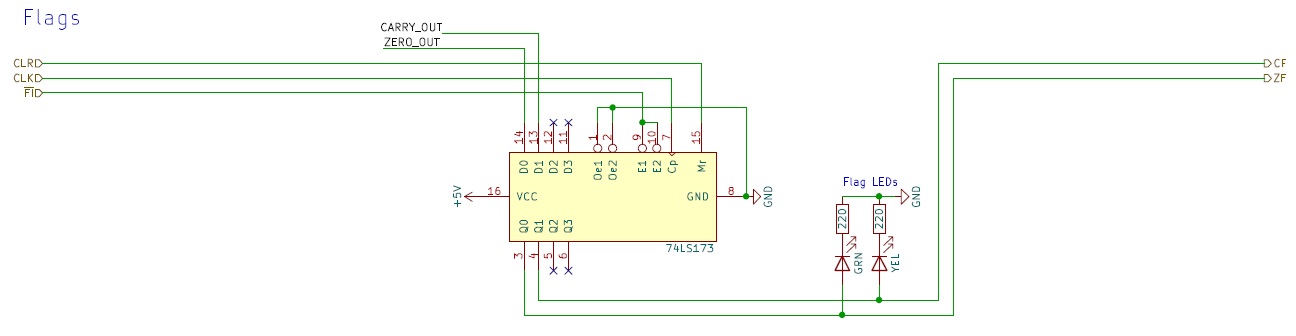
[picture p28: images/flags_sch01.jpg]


## Instruction Register

The Instruction Register itself is largely the same as what Ben Eater had for his build. Where it gets a little fuzzier is how I handled a couple additional Opcodes in hardware instead of at the Control Unit.

I really wanted to add the B Register Output (`/BO`) signal, and I also wanted to have an `/END` signal to tell my Microstep Counter to reset (instead of relying on it wrapping around). But, I only had 16 signals available to me, so I needed to either *drop* two signals, or find a way to address those outside the Control Unit. That's where the 74LS138 3-to-8 decoder comes in. I send it my 4-bit Opcode, and I also *tie* `/T2` from the Microstep Counter to one of it's enable PINs (`E1`). So, the chip only *comes alive* during `/T2` (which is where instructions are interpreted). If it receives an Opcode of 1111 (`/HLT`) it outputs LOW on PIN 7, and if it receives an Opcode of 1110 (`/SU`) it outputs LOW on PIN 6. For `/HLT`, I don't need to do anything special except send that up to the Clock module - everything stops. For `/SU`, that goes into an inverter and then gets latched on a seperate 74LS173 that is also enabled on `/T2`.

The other piece worth noting (mostly because I forgot until I was troubleshooting), is that the MSB nibble for the Instruction Register needs to be tied low or grounded (i.e. it can't send data to the bus). I suppose this only matters if you're allowing jump (`JMP`) instructions (which I am). The problem is that the Instruction receives data such as `01101010`, the MSB nibble is `0110`, which is the jump instruction. The LSB nibble is `1010` which is the address to jump to, and needs to be loaded into the Program Counter. If you output the entire Instruction Register to the bus (i.e. `01101010`), you'll actually be jumping to that address instead of `00001010` (which is what you want). This is obvious, but when my *task for the night* was to wire everything to the bus, I did just that :).

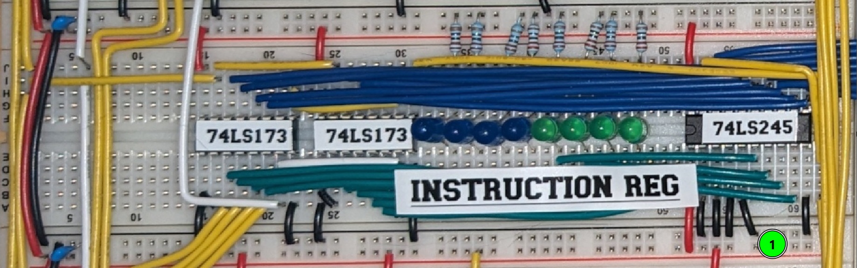
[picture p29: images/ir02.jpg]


- #1 - MSB nibble *tied low* so the Instruction Register can only output the LSB nibble

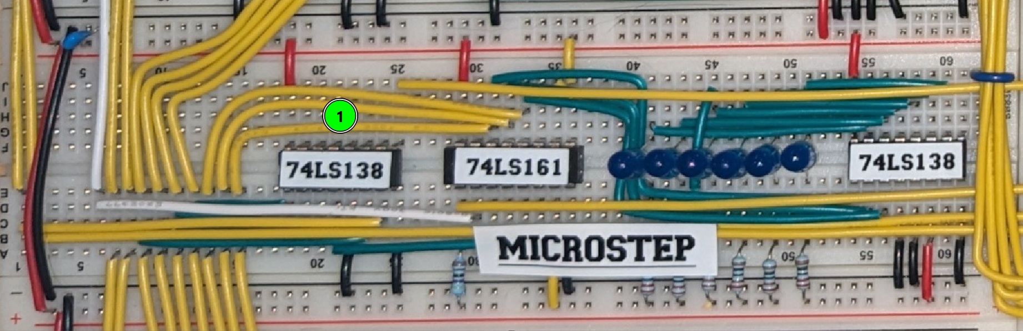
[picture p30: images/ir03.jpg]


- #1 - The 74LS138 I used to decode `/SU` and `/HLT`

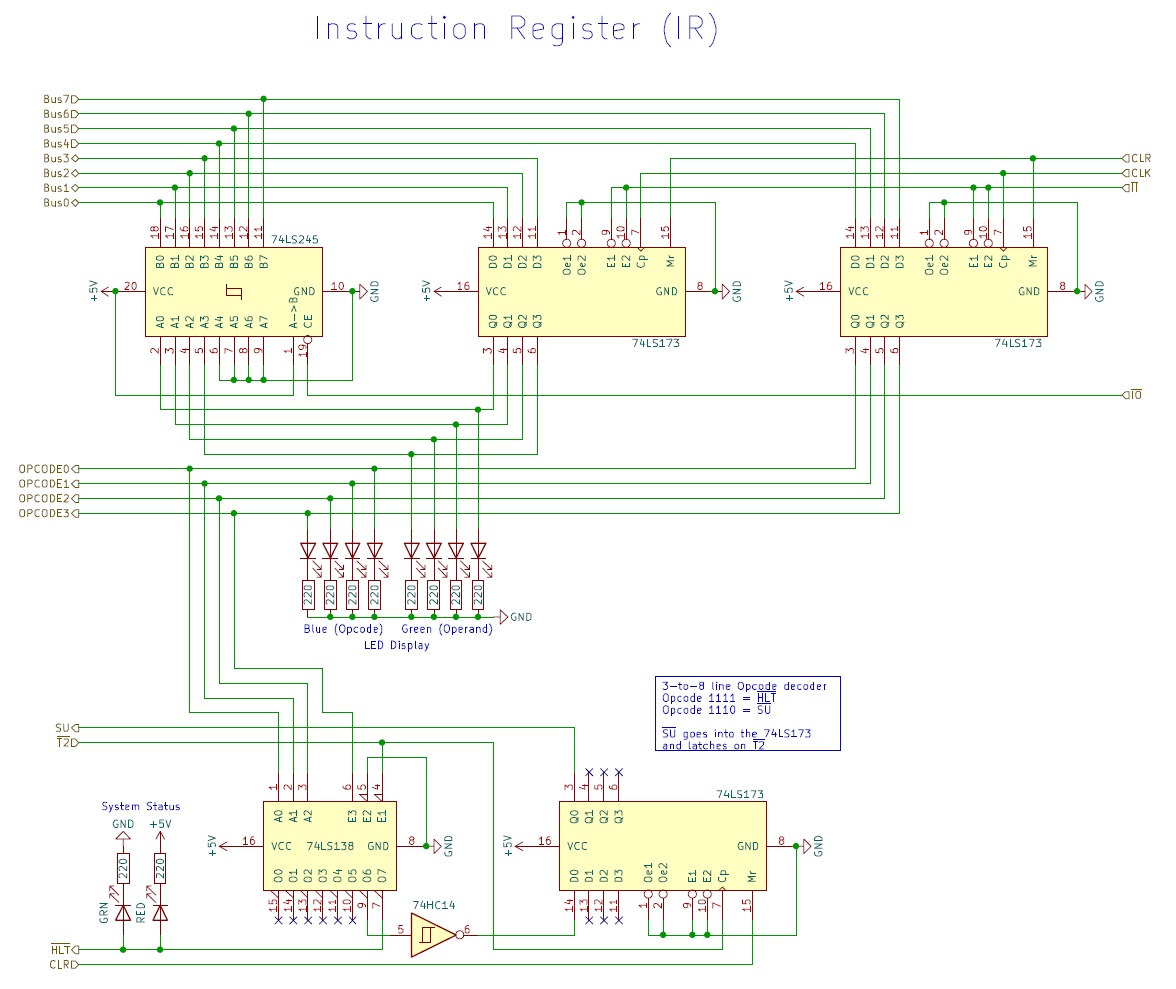
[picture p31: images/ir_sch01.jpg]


## Microstep Counter

Ignoring the *extra* 74LS138 (discussed above), this is pretty close to what Ben Eater had for his Microstep Counter. The only real modification I made was that I have a `/CLR_END` signal going into PIN 1 of the 74LS161. This will trigger if the Reset switch is pressed, or an `/END` control is signaled from the Control Unit (which happens at the end of every program step). Oh, and I flipped my LEDs to be active-low so only the current TStep was *on*.

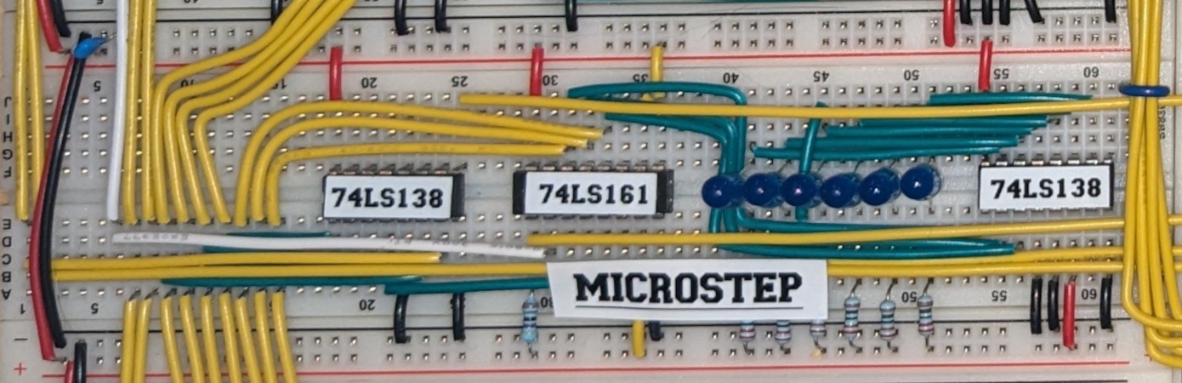
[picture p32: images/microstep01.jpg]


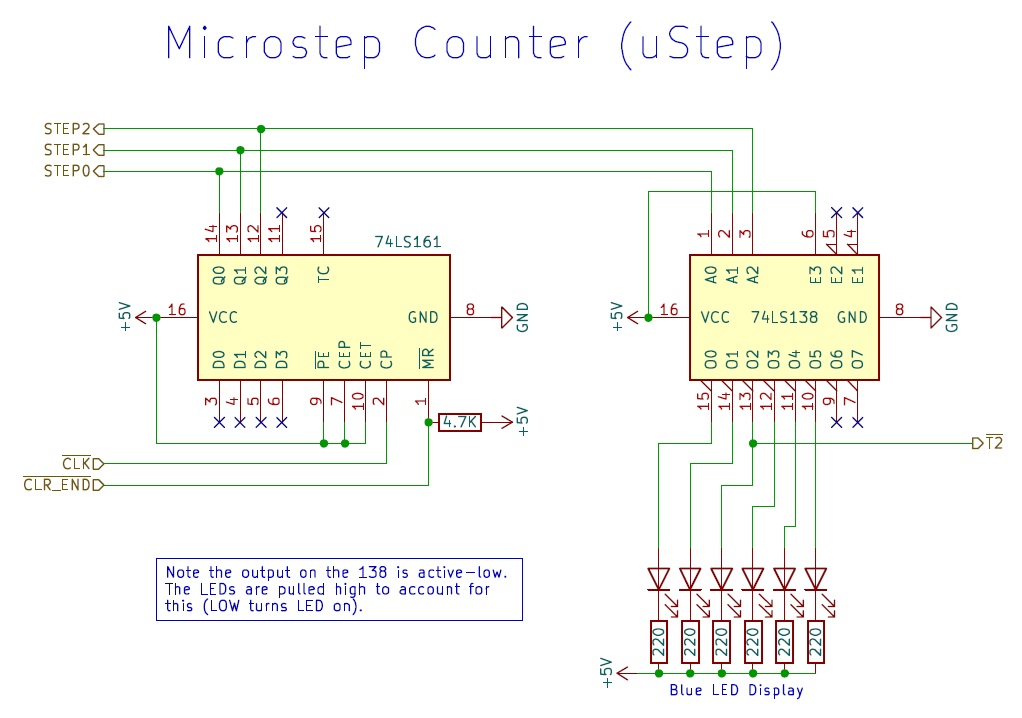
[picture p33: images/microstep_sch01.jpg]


## Auxiliary Board

For the most part, this board responsible for cleaning up or combining signals before they went *further up the board*.

Note that there's no dedicated schmatic for this board, as the chips are accounted for in other areas.

The 74LS08 (AND Gate) was only used to combine the `/END` (which is HIGH when it's off) and the `/CLR` (also HIGH when it's off) signals. If either of these went LOW, the resulting `CLR_END` signal would be LOW causing the Microstep Counter to reset. 

The 74HC14 (Schmitt Inverter) was used to invert the initial `/CLR` signal to produce a *clean* `CLR` signal (used by most of the board), and then again to produce a *clean* `/CLR` signal to be used by the Program Counter. It also inverted `/CE` (for the Program Counter) to `CE` (as it expects active-high).

The 74LS173 was only used to latch the value of `SU` (Subtract), and instead of latching on a Clock pulse, it latched on `/T2` from the Microstep Counter.

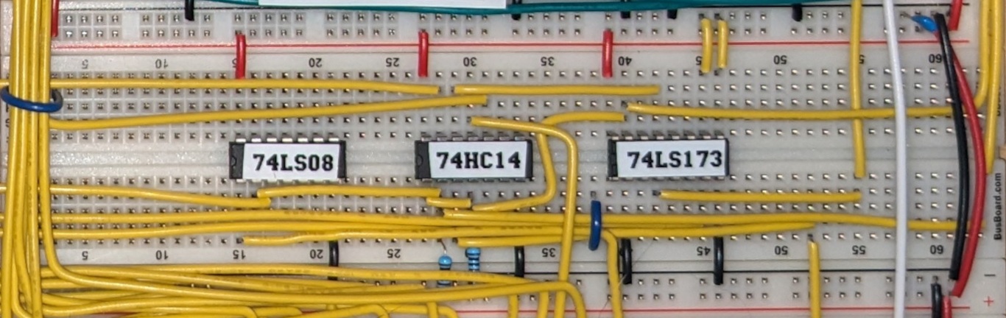
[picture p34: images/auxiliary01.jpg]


## Control Unit

The big one! My input logic and wiring was, I think, the same as Ben's here. Three wires from the Microstep Counter, four wires to represent the Opcode (from the Instruction Register), and two wires for the Flags (`CF`, `ZF`) - 9 inputs total.

I also utilized two separate EEPROM chips to take those 9 inputs and turn them into 8 + 8 = 16 total outputs.

I differed in the following areas...

I used two AT28C64B chips instead of 28C16s - I just couldn't find them easily.

My `/HLT` and `/SU` signals were taken care of *in hardware* directly instead of on the controller (this is addressed in #instruction-register).

I programmed all my control signals as active-low instead of active-high. This was a trade-off between more hardware to inverte high signals (as most of the chips wanted low signals), or working with potentially unintuitive programming where everything is a 1 except when it needs to do something - then it's a 0. Even in the truth table that I used to program the EEPROMs, I represent *active* as HIGH/1. Only when my `generate_microcode.py` Python script takes that truth table input and inverts it all is everything represetned as active-low proper.

For actual programming, I'd remove the chips from the board, put them onto [my programmer](/arduino/readme.md#eeprom-programmer), program them one at a time, then put them back onto the board. If I had more space, and had planned ahead, I might have put a *chip select* switch somewhere on the board to allow for easier programming.

The slide switch (#1 below) simply enables or disables the Control Unit via PIN 20 (`/CE`). I introduced this after continuously removing them to test my RAM. The problem is that, once power is supplied to the board (which you kind of need for RAM programming), the Control Unit is almost always trying to do something, and most (all) of those things get in the way of writing to or reading from RAM. So, my [RAM programmer](/arduino/readme.md#ram-programmer) would fail.

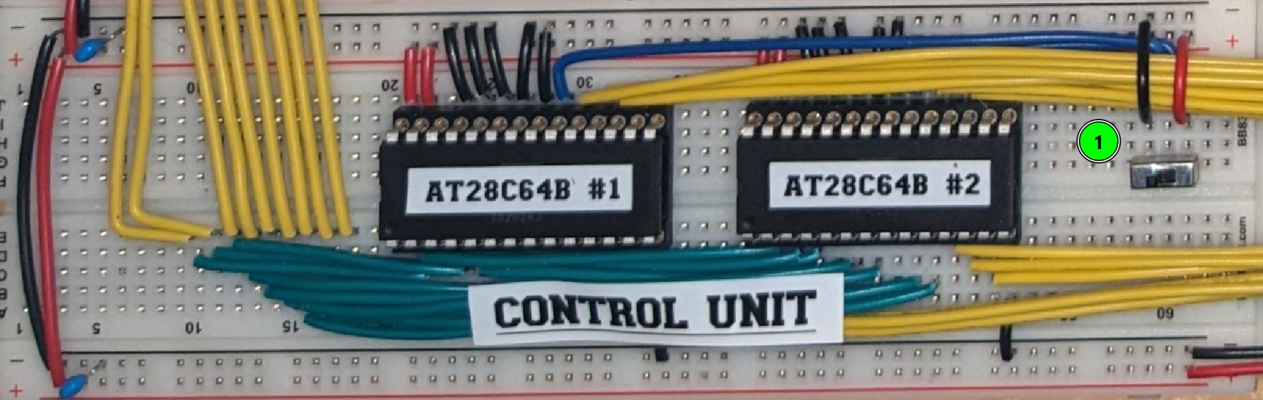
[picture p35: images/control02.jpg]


I'm happy with the way this LED panel turned out. I ordered mine by *Outputs*, *Inputs*, and *Other* control signals. And, of course, I color coded them :)

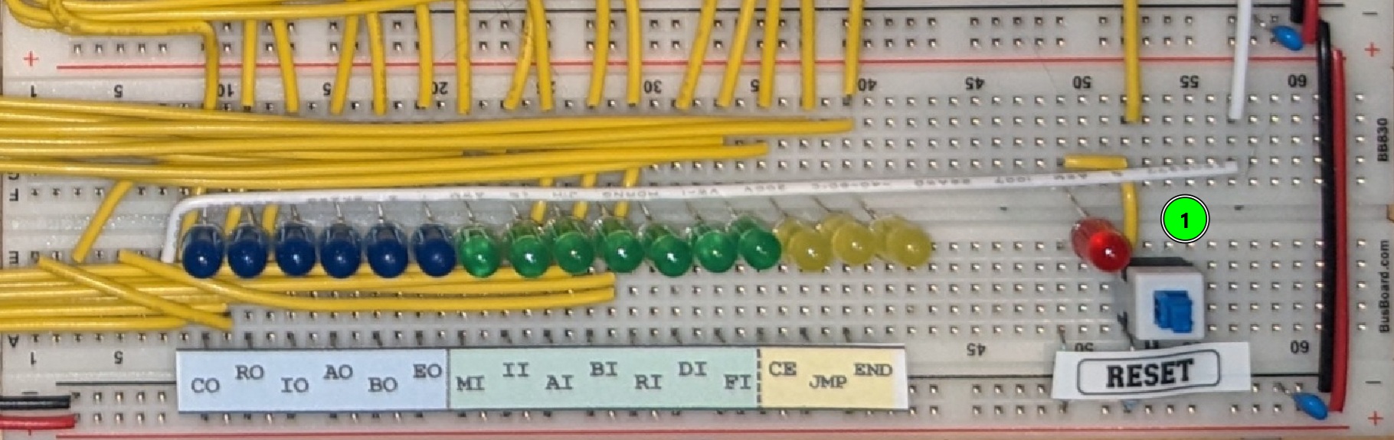
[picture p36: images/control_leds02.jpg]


#1 - This seemed like the right spot for this Reset switch

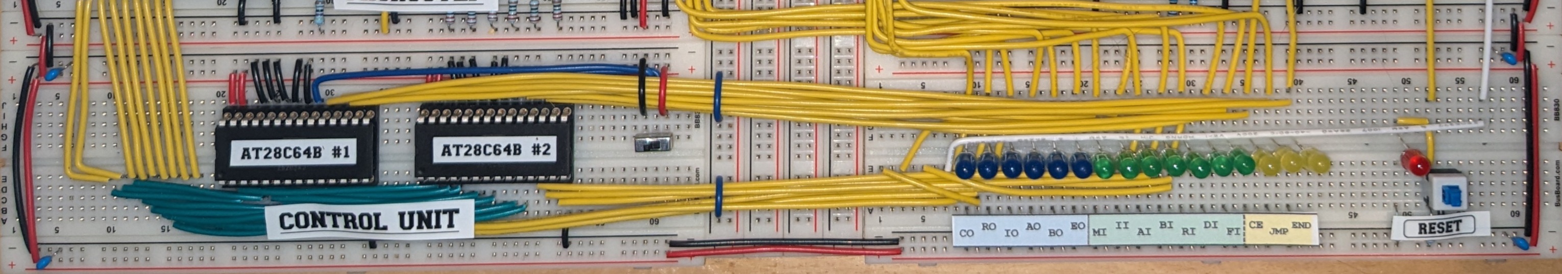
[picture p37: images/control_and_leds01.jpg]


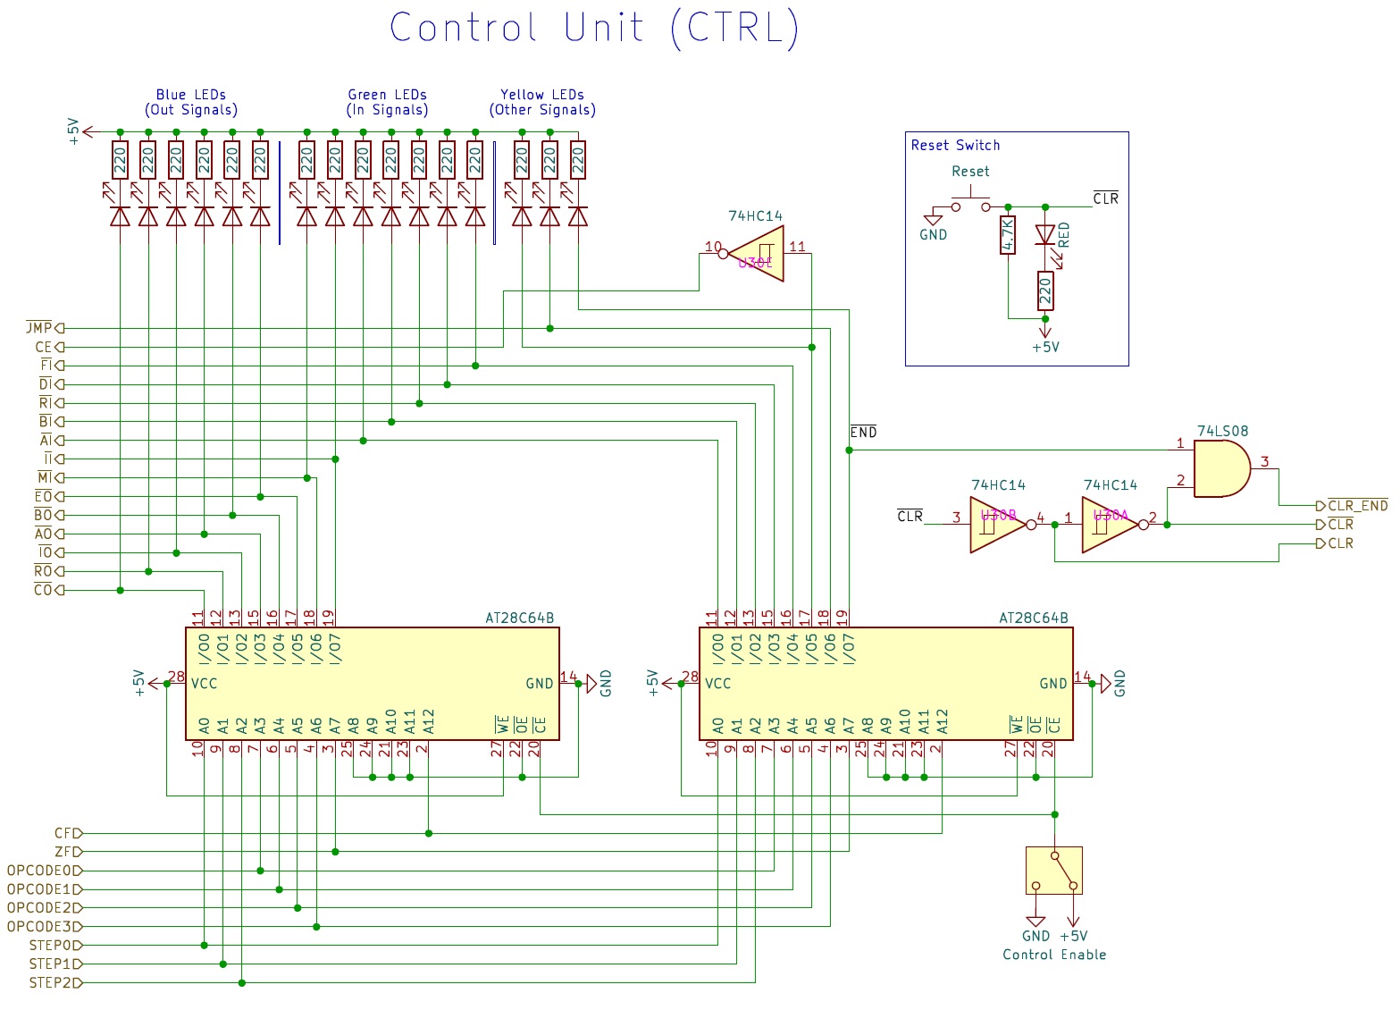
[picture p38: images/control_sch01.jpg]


## Assembly

For the most part, I assembled and built the project in the order described above. There are some progress photos [here](progress-photos.md).

At a high level, my build went as follows:
- Build and test the Clock.
- Build and test the Program Counter running of the Clock.
- Build the A & B Registers. Manually test their ability to latch input, clear, and put output onto the bus.
- Build the ALU, and manually test it's ability to take data from A & B Registers, and put output on to the bus. Worry about how you'll display it's data until later ;).
- Build and test the Display.
- Build and test the MAR.
- Build the RAM, connect it to the MAR, and test the interactions.
- Build the Instruction Register and test it's abilities (clear, take input, push to bus). Also, try not to forget to tie the MSB low going back to the bus (see [notes here] (#instruction-register));).
- Build the Microstep Counter, and make sure it can count. Also remember to have it active on `/CLK` vs. `CLK` everywhere else.
- Wire everything to the bus.
- Build and layout the the Control Unit
- Run control wires everywhere, and test every single one of them!
- [Write and test a program](/python/readme.md#microcode-generation) to convert your Control Unit truth table to actual EEPROM-usuable code.
- [Program](/arduino/readme.md#eeprom-programmer) the EEPROMs.
- Manually test some Opcodes to ensure signals are working as expected as you step through an instruction.
- [Write a program](/python/readme.md#compiling-programs) to generate *machine code* from your given instruction set/assembly language.
- [Program](/arduino/readme.md#ram-programmer) the RAM.
- Troubleshoot little things for days ;)

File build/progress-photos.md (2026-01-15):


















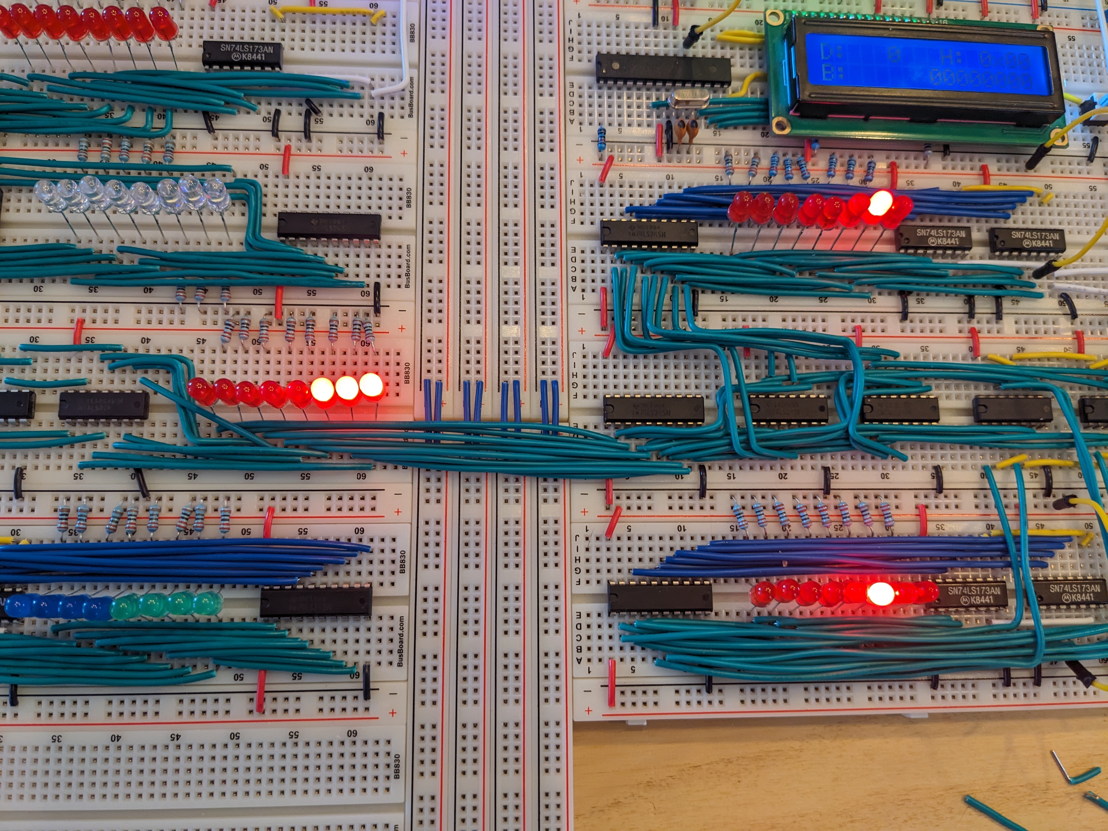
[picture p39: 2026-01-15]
images/build14.jpg

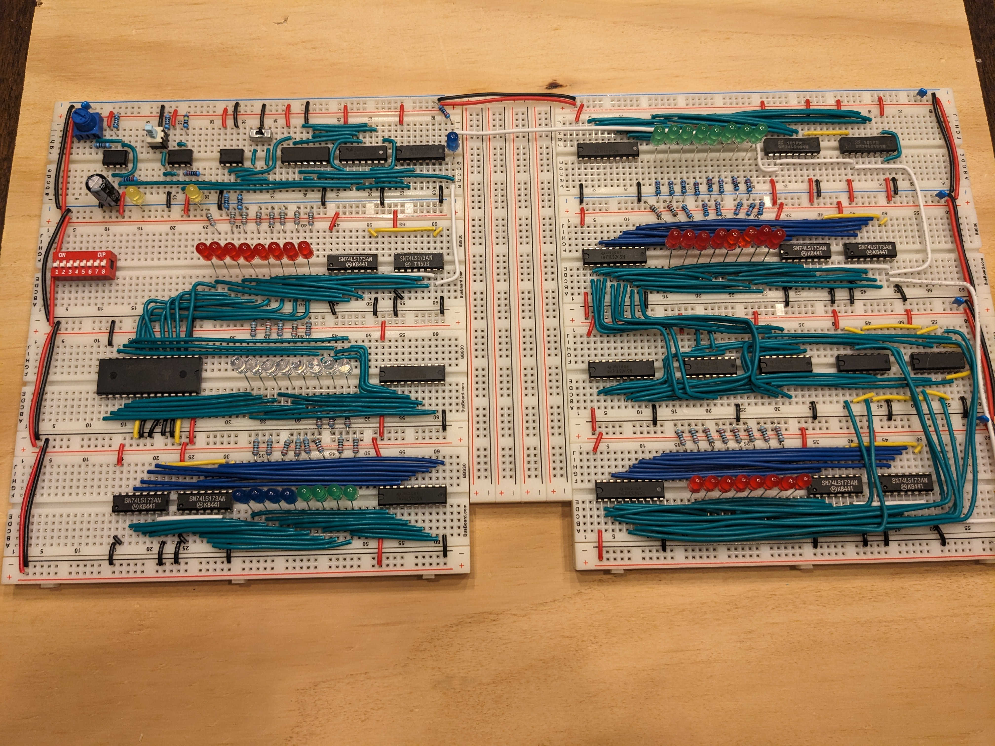
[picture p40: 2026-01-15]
images/build11.jpg

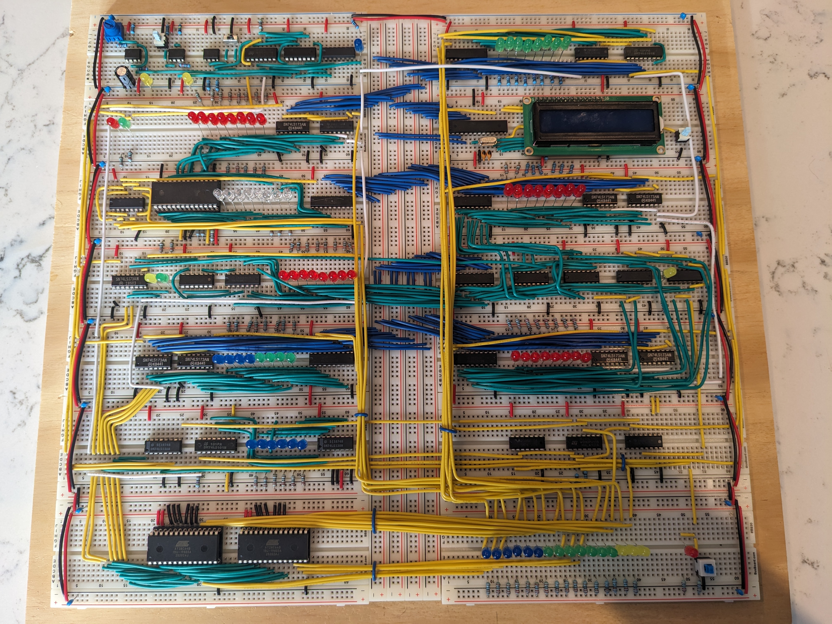
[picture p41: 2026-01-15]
images/build16.jpg

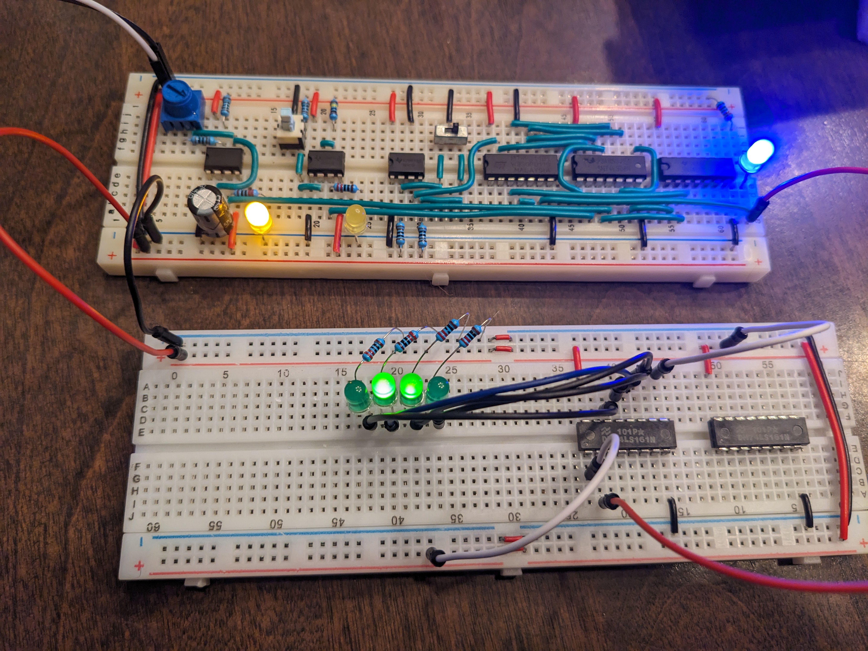
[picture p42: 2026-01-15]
images/build04.jpg

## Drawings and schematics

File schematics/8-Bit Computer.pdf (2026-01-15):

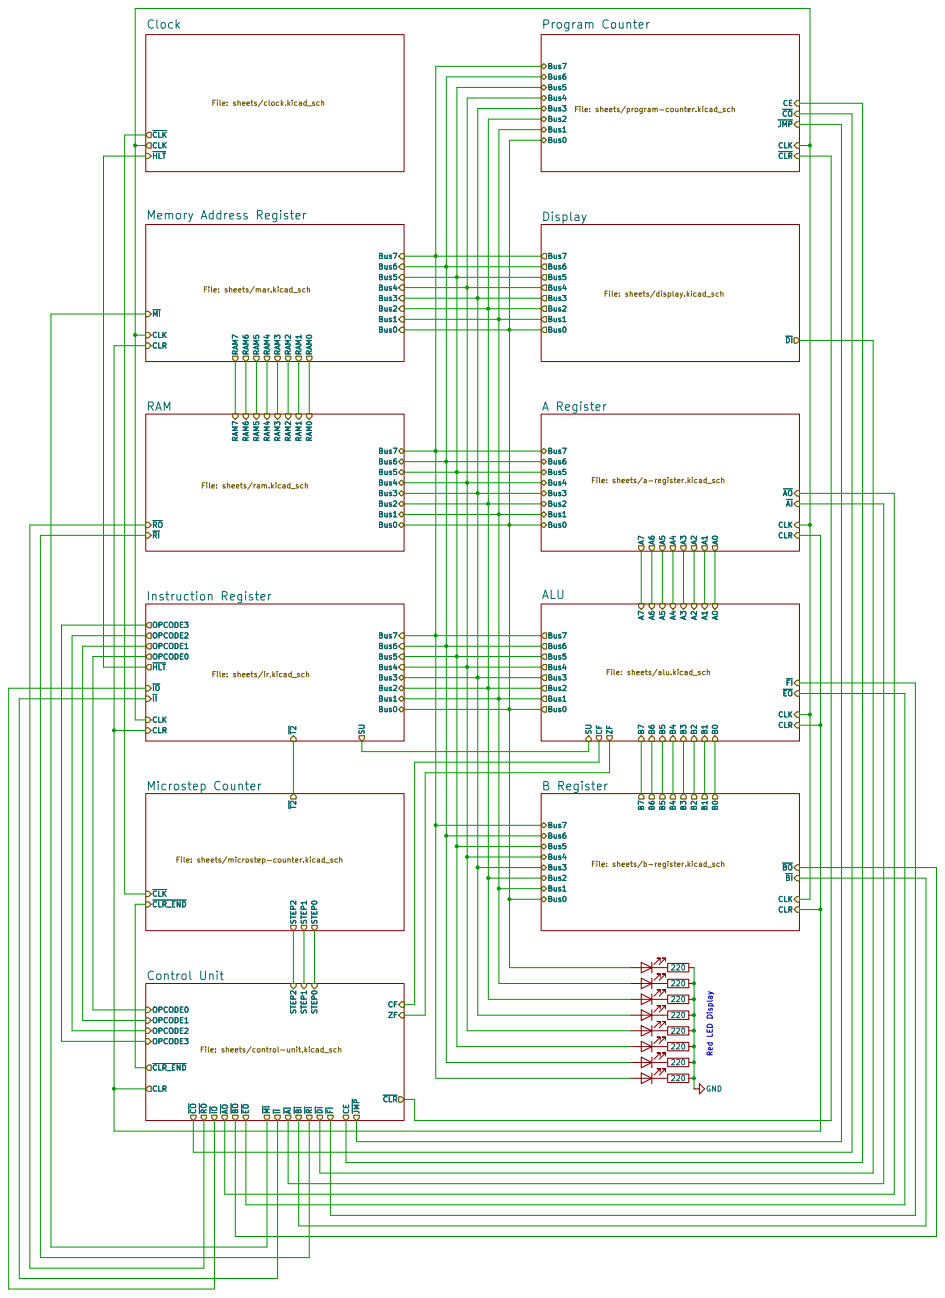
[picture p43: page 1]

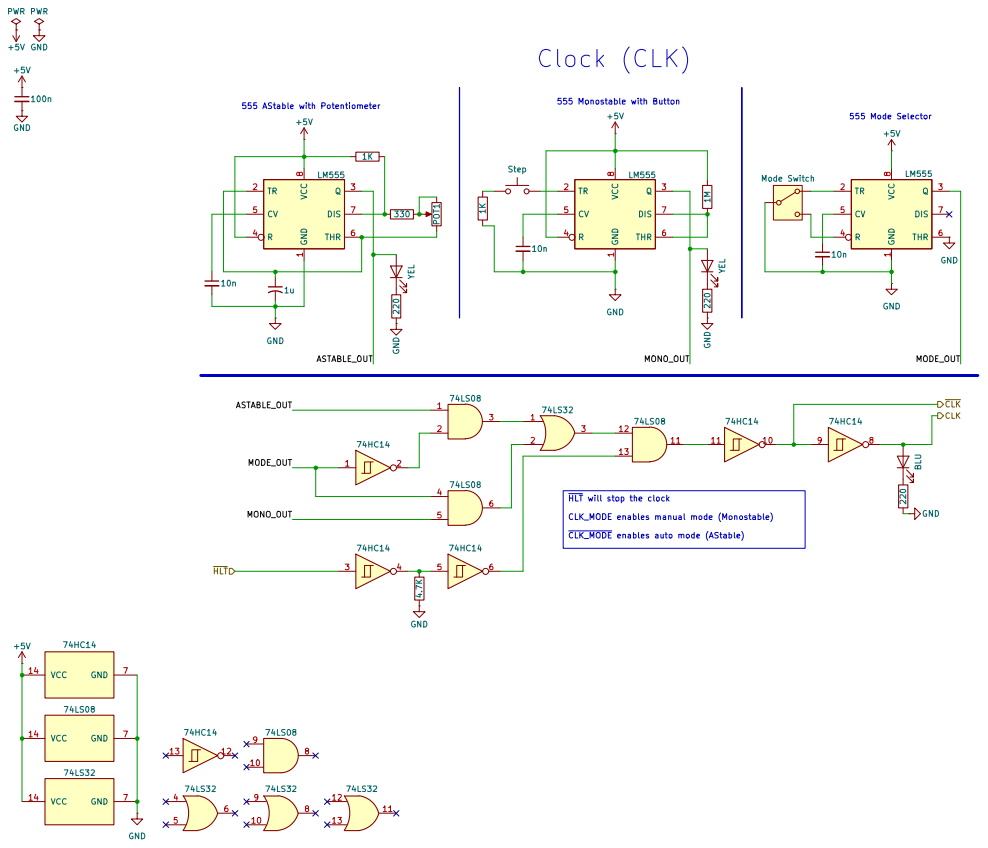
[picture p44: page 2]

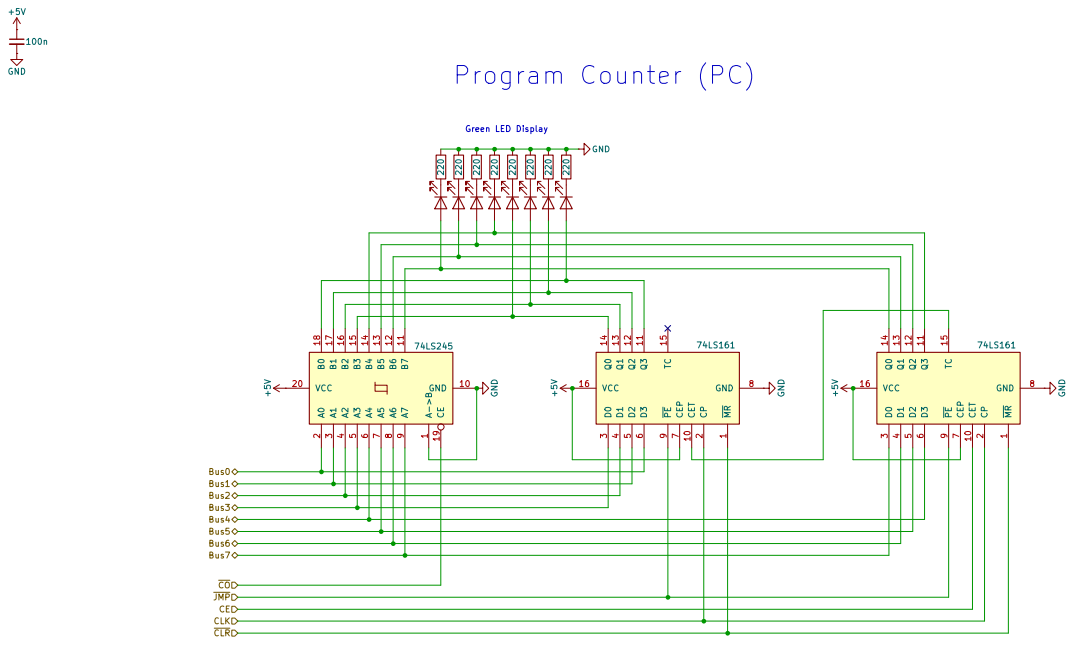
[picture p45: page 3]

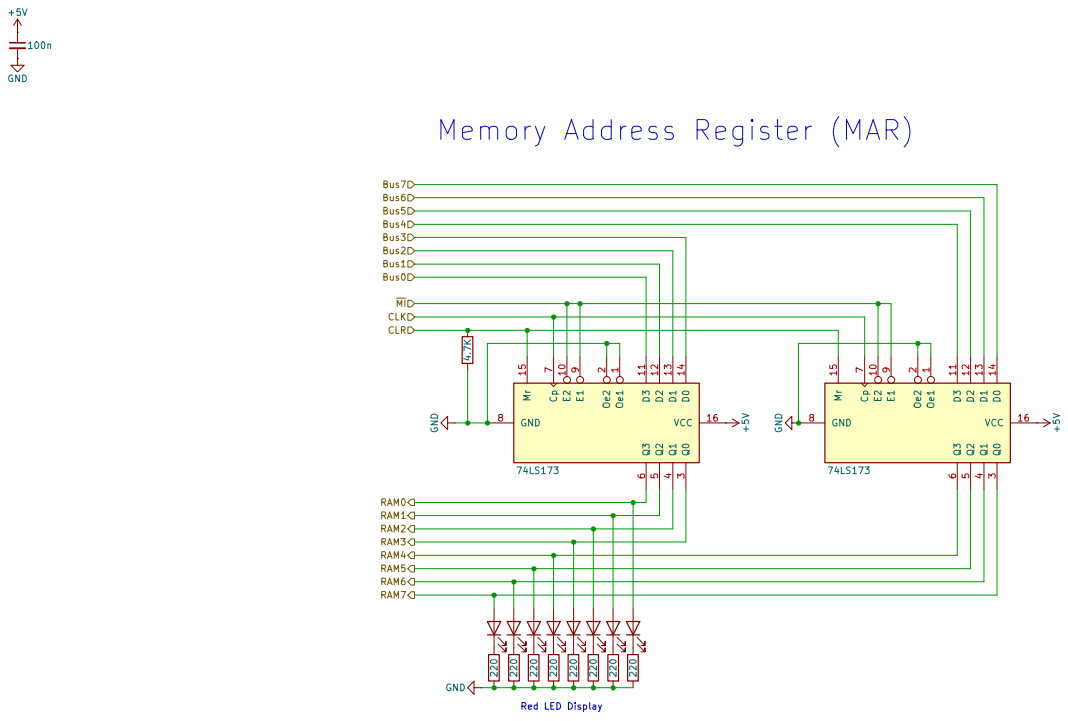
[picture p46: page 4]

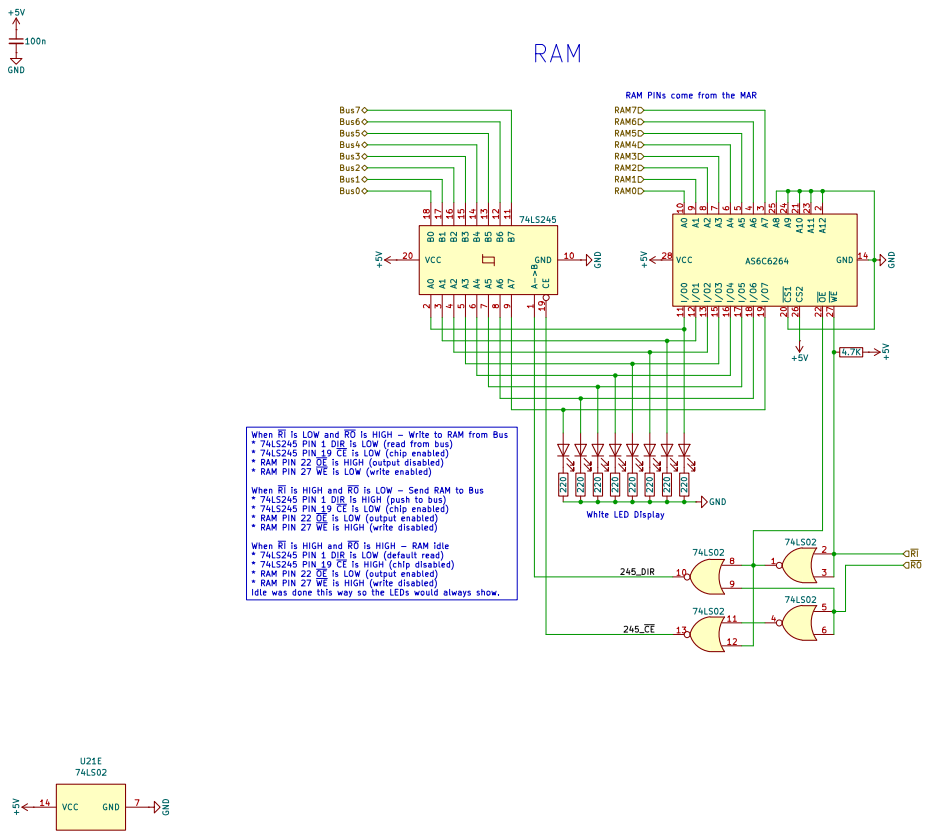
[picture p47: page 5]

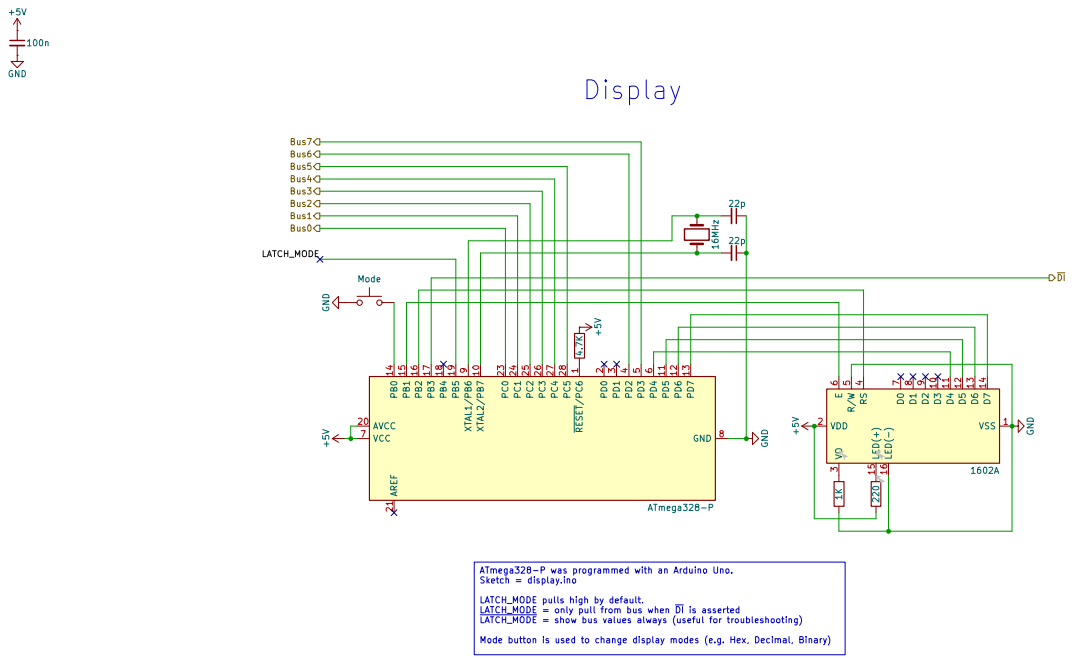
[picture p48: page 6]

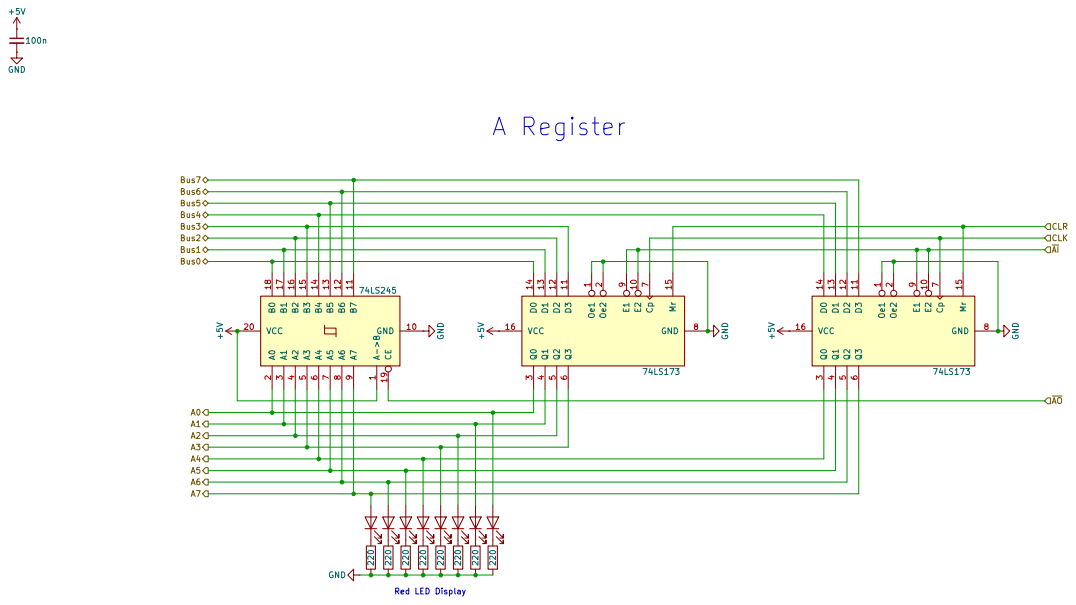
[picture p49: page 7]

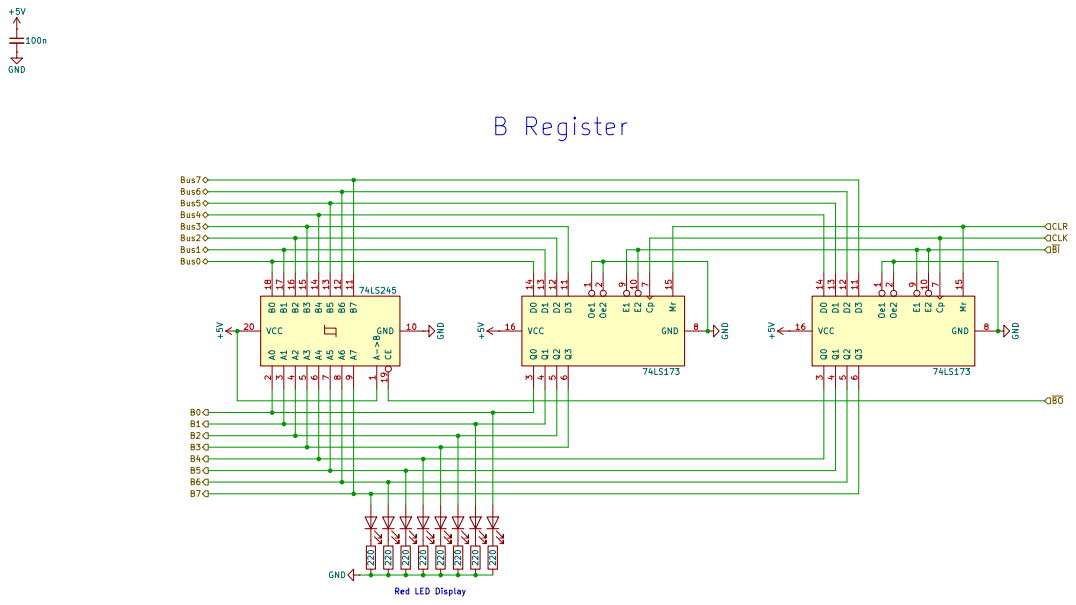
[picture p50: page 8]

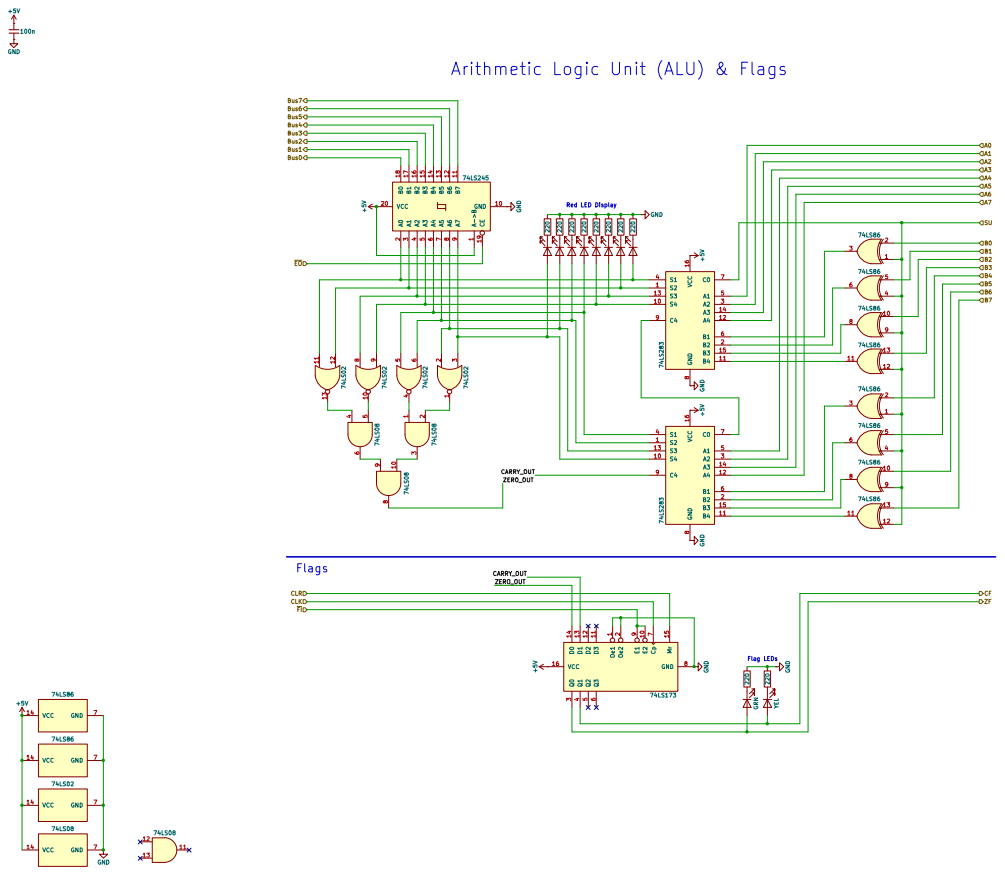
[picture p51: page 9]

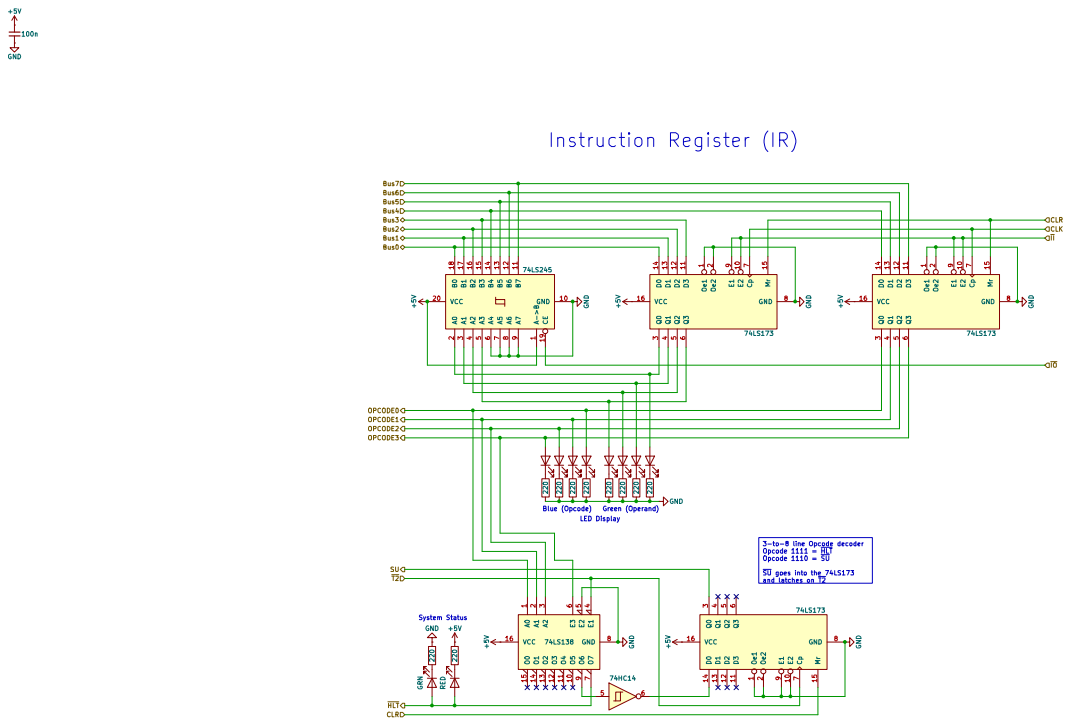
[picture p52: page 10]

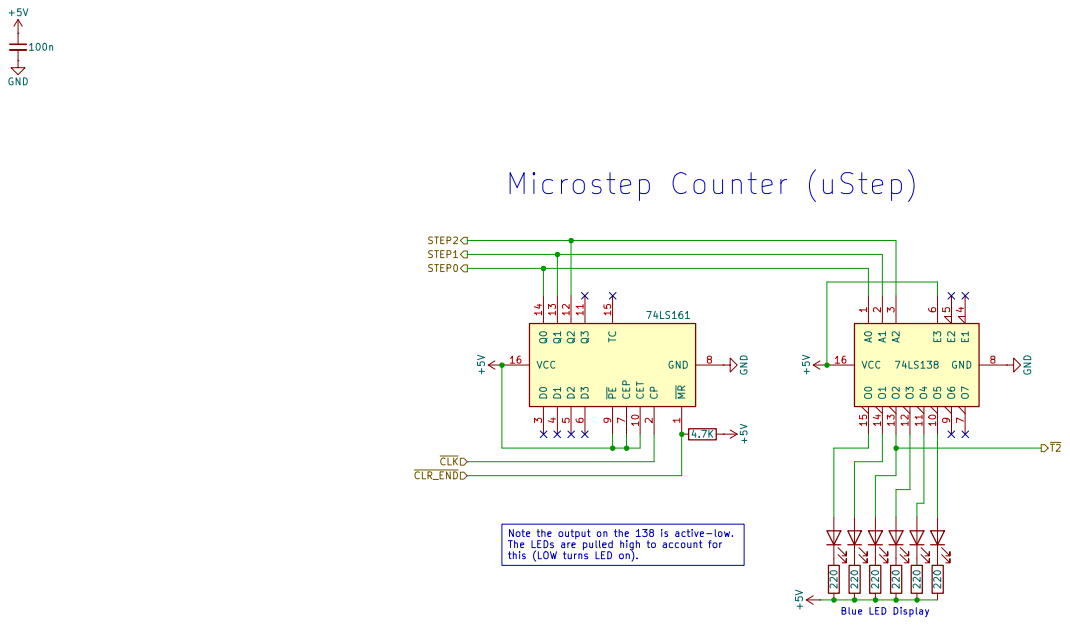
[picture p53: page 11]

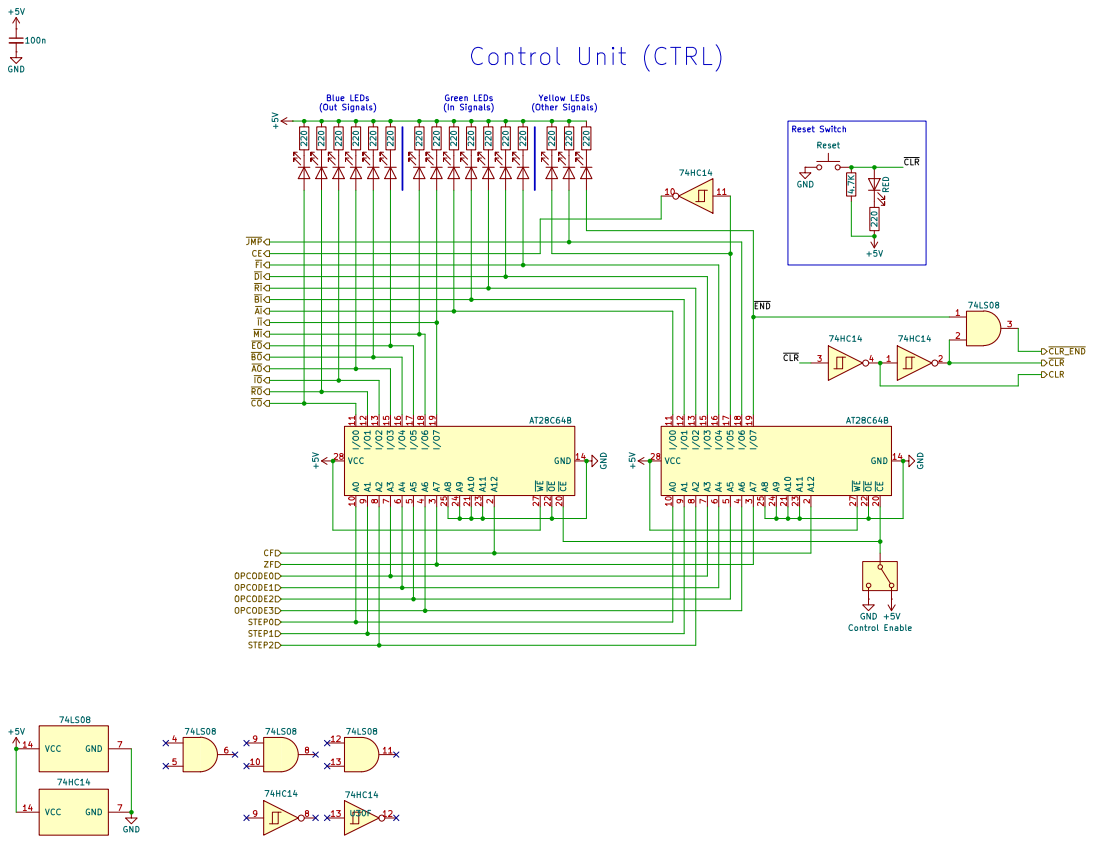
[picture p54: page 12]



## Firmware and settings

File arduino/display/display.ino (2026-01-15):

/*
This sketch sets up the 1602 LCD to display information from the 8-bit bus.
It has four 4 display modes:
* Binary  - e.g. BIN: 10101010
* Decimal - e.g. DEC:      252
* Hex     - e.g. HEX:       B3
* All     - combines all the above
* Secret  - Randomly selects a message :)
It expects the CPU to tell it to pull/latch from the bus via DISPLAY_OUT_PIN.
Primarily for debugging, there's also a BUS_MODE_PIN that, if set LOW, will constantly pull from the bus.
*/

#include <LiquidCrystal.h>

// initialize LCD PINs > Arduino PINs: RS, E, D4, D5, D6, D7
LiquidCrystal lcd(10, 9, 4, 5, 6, 7);

// data will come from the bus to be displayed on the LCD
// bus input pins
const uint8_t BUS_PINS[8] = {
  A0, // bus 0
  A1, // bus 1
  A2, // bus 2
  A3, // bus 3
  A4, // bus 4
  A5, // bus 5
  3,  // bus 6
  2   // bus 7
};

// mode button (hex, decimal, binary, all)
const uint8_t DISPLAY_MODE_PIN = 8;

// display output enable latch - sent from the CPU
const uint8_t DISPLAY_OUT_PIN = 11;

// bus mode pin (live or latch)
// HIGH = latch mode, LOW = live mode
const uint8_t BUS_MODE_PIN = 13;

// display modes
enum DisplayMode {
  MODE_BINARY = 0,
  MODE_DECIMAL = 1,
  MODE_HEX = 2,
  MODE_ALL = 3,
  MODE_SECRET = 4
};

// set the starting display mode
// Note: I set mine to hex as, upon booting, my board would send a low signal
//  and flip the mode to All...and I was too lazy to fix it in hardware :)
DisplayMode currentMode = MODE_HEX;

// debounced button state
uint8_t lastButtonState = HIGH;
unsigned long lastDebounceTime = 0;
const unsigned long debounceDelay = 50; // ms

// edge-detect for latch signal (DISPLAY_OUT_PIN)
uint8_t lastDisplayOutState = HIGH;

// used for some secret messaging
bool SECRETS_ENABLED = true;
uint8_t secretValue = 0;
bool secretGenerated = false;
const char* secretMessages[] = {
  "I love Danielle",
  "I love Theo",
  "I love Alex",
};

// bus values
uint8_t latchedBusValue = 0;   // value captured in latch mode
uint8_t liveBusValue = 0;      // latest sampled value in live mode
uint8_t displayValue = 0;      // value currently shown on LCD

// mode-change flag so we refresh when format changes
bool modeChanged = true;

// live-mode sampling throttle
const unsigned long liveUpdateInterval = 100; // ms
unsigned long lastLiveSampleTime = 0;

// ---------- FUNCTIONS ----------

void handleModeButton() {
  int reading = digitalRead(DISPLAY_MODE_PIN);

  // if the state changed, restart the debounce timer
  if (reading != lastButtonState) {
    lastDebounceTime = millis();
  }

  // if stable long enough, treat as real state
  if ((millis() - lastDebounceTime) > debounceDelay) {
    // edge detection on a debounced state
    static uint8_t stableState = HIGH;

    if (reading != stableState) {
      stableState = reading;

      // button pressed - switch modes
      if (stableState == LOW) {
        if (currentMode == MODE_BINARY) {
          currentMode = MODE_DECIMAL;
        } else if (currentMode == MODE_DECIMAL) {
          currentMode = MODE_HEX;
        } else if (currentMode == MODE_HEX) {
          currentMode = MODE_ALL;
        } else if (currentMode == MODE_ALL) {
          if (SECRETS_ENABLED) {
            secretGenerated = false;
            currentMode = MODE_SECRET;
          } else {
            currentMode = MODE_BINARY;
          }
        } else if (currentMode == MODE_SECRET) {
          currentMode = MODE_BINARY;
        }

        modeChanged = true;
      }
    }
  }

  lastButtonState = reading;
}

void handleDisplayOutSignal() {
  uint8_t displayOutState = digitalRead(DISPLAY_OUT_PIN);

  // detect rising edge: HIGH --> LOW
  if (lastDisplayOutState == HIGH && displayOutState == LOW) {
    latchedBusValue = readBus();
  }

  lastDisplayOutState = displayOutState;
}

void handleBusLiveSampling() {
  unsigned long now = millis();
  
  // make sure we're at or past our update interval
  if (now - lastLiveSampleTime < liveUpdateInterval) {
    return;
  }

  lastLiveSampleTime = now;
  liveBusValue = readBus();
}

// get the values from the bus
uint8_t readBus() {
  uint8_t value = 0;
  for (uint8_t bit = 0; bit < 8; bit++) {
    int pinState = digitalRead(BUS_PINS[bit]);
    if (pinState == HIGH) {
      value |= (1 << bit);
    }
  }
  return value;
}

void updateDisplay(uint8_t value) {
  lcd.clear();

  char line0[17];
  char line1[17];

  // create the binary string
  char binStr[9];
  for (int i = 7; i >= 0; i--) {
    binStr[7 - i] = (value & (1 << i)) ? '1' : '0';
  }
  binStr[8] = '\0';

  switch (currentMode) {
    case MODE_BINARY: {
      snprintf(line0, sizeof(line0), "BIN:    %s", binStr);
      snprintf(line1, sizeof(line1), "");
      break;
    }

    case MODE_DECIMAL:
      snprintf(line0, sizeof(line0), "DEC:%12u", value);
      snprintf(line1, sizeof(line1), "");
      break;

    case MODE_HEX:
      snprintf(line0, sizeof(line0), "HEX:%8s0x%02X", "", value);
      snprintf(line1, sizeof(line1), "");
      break;

    case MODE_ALL:
      snprintf(line0, sizeof(line0), "D:%4u   H: 0x%02X", value, value);
      snprintf(line1, sizeof(line1), "B:      %s", binStr);
      break;

    // you can have the display randomly show some phrases - just for fun
    case MODE_SECRET:
      if (!secretGenerated) {
        const uint8_t NUM_SECRETS = sizeof(secretMessages) / sizeof(secretMessages[0]);
        secretValue = random(NUM_SECRETS);
        secretGenerated = true;
      }

      snprintf(line0, sizeof(line0), "%s", secretMessages[secretValue]);
      snprintf(line1, sizeof(line1), "");
      break;
  }

  lcd.setCursor(0, 0);
  lcd.print(line0);
  lcd.setCursor(0, 1);
  lcd.print(line1);
}

// ---------- SETUP ----------

void setup() {
  randomSeed(analogRead(A6));

  // bus mode pin: default HIGH (latch mode) via pullup
  pinMode(BUS_MODE_PIN, INPUT_PULLUP);

  // bus pins as inputs
  for (uint8_t i = 0; i < 8; i++) {
    pinMode(BUS_PINS[i], INPUT);
  }

  // mode button with pullup
  pinMode(DISPLAY_MODE_PIN, INPUT_PULLUP);

  // display out pin
  pinMode(DISPLAY_OUT_PIN, INPUT_PULLUP);
  lastDisplayOutState = digitalRead(DISPLAY_OUT_PIN);
  
  // initialize and clear the display
  lcd.begin(16, 2);
  lcd.clear();

  // show a brief message before showing data: 8-bit Computer :)
  lcd.setCursor(0, 0);
  lcd.print("8-bit Computer");
  lcd.setCursor(0, 1);
  lcd.print(":)");
  delay(1000);

  // initialize button debounce state from actual pin
  lastButtonState = digitalRead(DISPLAY_MODE_PIN);
  lastDebounceTime = millis();

  // initial bus values
  uint8_t initial = readBus();
  latchedBusValue = initial;
  liveBusValue = initial;
  displayValue = initial;

  updateDisplay(displayValue);
}

// ---------- MAIN LOOP ----------

void loop() {
  // handle mode (BIN/DEC/HEX/ALL/SECRET) button
  handleModeButton();

  // HIGH = latch mode, LOW = live mode
  bool latchMode = (digitalRead(BUS_MODE_PIN) == HIGH);

  if (latchMode) {
    handleDisplayOutSignal();
  } else {
    handleBusLiveSampling();
  }

  // decide which value should be displayed
  uint8_t desiredValue = latchMode ? latchedBusValue : liveBusValue;

  // only redraw if value changed or mode changed
  if (desiredValue != displayValue || modeChanged) {
    displayValue = desiredValue;
    updateDisplay(displayValue);
    modeChanged = false;
  }

  delay(1);
}

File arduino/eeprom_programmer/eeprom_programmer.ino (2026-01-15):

/*
This sketch programs the EEPROMs (AT28C64B).
You'll be prompted to select which chip to program.

Assumptions:
* You've already generated microcode_images.h via generate_microcode.py.
* You're using two 74-595 shift registers for programming.

The EEPROMs were removed from the project and programmed individually, then
put back into the project.
Expected wiring:
* Arduino D2  > EEPROM PIN 11 (DQ0)
* Arduino D3  > EEPROM PIN 12 (DQ1)
* Arduino D4  > EEPROM PIN 13 (DQ2)
* Arduino D5  > EEPROM PIN 15 (DQ3)
* Arduino D6  > EEPROM PIN 16 (DQ4)
* Arduino D7  > EEPROM PIN 17 (DQ5)
* Arduino D8  > EEPROM PIN 18 (DQ6)
* Arduino D9  > EEPROM PIN 19 (DQ7)
* Arduino D10 > 595-LSB PIN 14 (SER)
* Arduino D11 > 595-* PIN 11 (SRCK) 
* Arduino D12 > 595-* PIN 12 (RCK)
* Arduino A0  > EEPROM PIN 27 (/WE)
* Arduino A1  > EEPROM PIN 22 (/OE)
*/

#include <Arduino.h>
#include <avr/pgmspace.h>
#include "microcode_images.h"   // this is generated automatically via generate_microcode.py

// ---------------- 74HC595 PINs ----------------
const int PIN_SER  = 10;  // PIN 14 - SER
const int PIN_SRCK = 11;  // PIN 11 - SRCK
const int PIN_RCK  = 12;  // PIN 12 - RCK

// ---------------- EEPROM PINs ----------------
const int PIN_WE = A0;    // PIN 27 - /WE
const int PIN_OE = A1;    // PIN 22 - /OE

// ---------------- EEPROM Data PINs ----------------
const int DATA_PINS[8] = {2,3,4,5,6,7,8,9};

// ---------------- Timing ----------------
static const unsigned int ADDR_SETTLE_US = 2;
static const unsigned int DATA_SETTLE_US = 2;
static const unsigned int WE_PULSE_US    = 3;
static const unsigned int WRITE_CYCLE_MS = 10;

// retries per address
static const int WRITE_RETRIES = 3;

// ---------------- data bus helpers ----------------
static inline void setDataBusOutput() { for (int i=0;i<8;i++) pinMode(DATA_PINS[i], OUTPUT); }
static inline void setDataBusInput()  { for (int i=0;i<8;i++) pinMode(DATA_PINS[i], INPUT);  }

static inline void writeDataBus(uint8_t v){
  for (int i=0;i<8;i++) digitalWrite(DATA_PINS[i], (v >> i) & 1);
}

static inline uint8_t readDataBus(){
  uint8_t v = 0;
  for (int i=0;i<8;i++) if (digitalRead(DATA_PINS[i])) v |= (1 << i);
  return v;
}

static void printBits(uint8_t v) {
  for (int i = 7; i >= 0; i--) Serial.print((v >> i) & 1);
}

static void printDiff(uint8_t expected, uint8_t got) {
  Serial.print("  exp 0b"); printBits(expected);
  Serial.print(" (0x"); if (expected < 16) Serial.print('0'); Serial.print(expected, HEX); Serial.println(")");
  Serial.print("  got 0b"); printBits(got);
  Serial.print(" (0x"); if (got < 16) Serial.print('0'); Serial.print(got, HEX); Serial.println(")");
}

void setAddress(uint16_t addr){
  uint8_t low  = (uint8_t)(addr & 0xFF);
  uint8_t bit8 = (uint8_t)((addr >> 8) & 0x01);

  uint8_t high = 0;
  high |= (bit8 << 1); // QB

  // be safe while changing addresses
  digitalWrite(PIN_WE, HIGH);
  digitalWrite(PIN_OE, HIGH);

  digitalWrite(PIN_RCK, LOW);
  shiftOut(PIN_SER, PIN_SRCK, MSBFIRST, high); // 595 #2
  shiftOut(PIN_SER, PIN_SRCK, MSBFIRST, low);  // 595 #1
  digitalWrite(PIN_RCK, HIGH);

  delayMicroseconds(ADDR_SETTLE_US);
}

static inline void pulseWE(){
  digitalWrite(PIN_WE, LOW);
  delayMicroseconds(WE_PULSE_US);
  digitalWrite(PIN_WE, HIGH);
}

void writeEEPROM(uint16_t addr, uint8_t data){
  digitalWrite(PIN_OE, HIGH);  // disable output during write
  digitalWrite(PIN_WE, HIGH);

  setAddress(addr);

  setDataBusOutput();
  writeDataBus(data);
  delayMicroseconds(DATA_SETTLE_US);

  pulseWE();
  delay(WRITE_CYCLE_MS);
}

uint8_t readEEPROM(uint16_t addr){
  digitalWrite(PIN_WE, HIGH);
  setAddress(addr);

  setDataBusInput();
  digitalWrite(PIN_OE, LOW);
  delayMicroseconds(DATA_SETTLE_US);

  uint8_t v = readDataBus();

  digitalWrite(PIN_OE, HIGH);
  return v;
}

bool writeAndVerify(uint16_t addr, uint8_t data, int retries=WRITE_RETRIES){
  for(int attempt=1; attempt<=retries; attempt++){
    writeEEPROM(addr, data);
    uint8_t got = readEEPROM(addr);
    if(got == data) return true;

    Serial.print("Mismatch @0x");
    Serial.print(addr, HEX);
    Serial.print(" attempt ");
    Serial.println(attempt);
    printDiff(data, got);
  }
  return false;
}

const uint8_t* chooseImageByChar(char c){
  if (c == '1') return EEPROM1_IMAGE;
  if (c == '2') return EEPROM2_IMAGE;
  return nullptr;
}

/*
this test detects:
* stuck bits (always 1 or always 0)
* swapped data lines (walking-bit comes back on the wrong bit)
* weak/float lines (intermittent mismatch)
*/
bool dataBusSelfTest(uint16_t addr = 0x000){
  Serial.println("Pre-flight test - walking 1s and walking 0s...");
  bool ok = true;

  // walking 1s
  for (uint8_t bit = 0; bit < 8; bit++) {
    uint8_t v = (uint8_t)(1u << bit);
    if(!writeAndVerify(addr, v, 2)){
      Serial.print("DQ test FAIL (walking 1) bit ");
      Serial.println(bit);
      ok = false;
    }
  }

  // walking 0s
  for (uint8_t bit = 0; bit < 8; bit++) {
    uint8_t v = (uint8_t)~(1u << bit);
    if(!writeAndVerify(addr, v, 2)){
      Serial.print("DQ test FAIL (walking 0) bit ");
      Serial.println(bit);
      ok = false;
    }
  }

  Serial.println(ok ? "PASS" : "FAIL");
  return ok;
}

bool programImage(const uint8_t* imageProgmem){
  const uint16_t SIZE = 512;

  Serial.println("Programming...");
  for(uint16_t addr=0; addr<SIZE; addr++){
    uint8_t expected = pgm_read_byte_near(imageProgmem + addr);

    if(!writeAndVerify(addr, expected, WRITE_RETRIES)){
      Serial.print("HARD FAIL: 0x");
      Serial.println(addr, HEX);
      return false;
    }

    // write status every 64 bytes
    if ((addr & 0x3F) == 0) {
      Serial.print("  Wrote and verified up to: 0x");
      Serial.println(addr, HEX);
    }
  }
  Serial.println("Write complete.");
  return true;
}

bool finalVerify(const uint8_t* imageProgmem){
  const uint16_t SIZE = 512;
  Serial.println("Final verification pass...");
  uint16_t bad = 0;

  for(uint16_t addr=0; addr<SIZE; addr++){
    uint8_t expected = pgm_read_byte_near(imageProgmem + addr);
    uint8_t got      = readEEPROM(addr);

    if(got != expected){
      bad++;
      if (bad <= 20) {
        Serial.print("Mismatch: 0x");
        Serial.println(addr, HEX);
        printDiff(expected, got);
      }
    }
  }

  Serial.print("Final verification done. Bad bytes: ");
  Serial.println(bad);
  return bad == 0;
}
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
